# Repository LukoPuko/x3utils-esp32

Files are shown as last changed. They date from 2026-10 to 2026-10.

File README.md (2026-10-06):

# x3utils-esp32

A **standalone ESP32 flasher for the AT32F415 VCU** on X3-family e-scooters
(ZT3 Pro, Max G3, F3 / F3 Pro), controlled entirely from your **phone's browser
over WiFi**.

No PC. No ST-LINK. No app install. The ESP32 *is* the programmer: it bit-bangs
SWD to the scooter's debug pins itself, and hosts a web UI you drive from
Safari on an iPhone (or any browser — WiFi, so the Chrome/WebUSB limitation of
the original web app does not apply).

This is an ESP32 port of [**x3utils**](https://github.com/ztakis/x3utils). The
flashing *brains* — the AT32F415 erase/program/verify sequence, the FAP
read-protection check and rescue, the SHU-compatibility patch and its firmware
safety gates — are ported straight from the upstream engine. Only the transport
changed: an ESP32 GPIO SWD master replaces the ST-LINK, and a built-in web
server replaces the desktop GUI.

> [!WARNING]
> This tool writes the scooter VCU directly. A wrong file, a bad contact, or an
> interrupted flash can leave the controller unusable until recovered. **Always
> make a full backup first and keep it safe.** Use 3.3 V logic only, and power
> the VCU from **one** source at a time.

> [!IMPORTANT]
> **On-hardware validation status.** The firmware-identity / SHU-compat safety
> gates and the Thumb-2 version decoder are covered by host unit tests (see
> `host_test/`). The bit-banged SWD transaction layer (`swd.cpp`) follows the
> standard ADIv5 framing but has **not** been bench-verified against a real
> AT32F415 in this repository's CI (none exists). Treat your first connection as
> a bring-up: start with **Check connection** and **Backup**, confirm a clean
> 128 KB read, and only then flash. If you see `no ACK` / parity errors, raise
> the **SWD half-clock µs** setting (1–3) for a slower, more tolerant line.

---

## What it does

Same operations as the desktop/web app, from the browser:

- **Check connection** — read-only probe + target identification.
- **Backup 128 KB** — full dump, validated, downloaded to your phone as a `.bin`.
- **Backup + Flash** — upload a full 128 KB `.bin`; it erases, writes, verifies.
- **Flash slot 0** — upload a slot-0 `.bin` (identity-preserving).
- **Check protection** — read-only FAP (read-protection) verdict.
- **Unlock / Rescue** — clears FAP; this **mass-erases** main flash (recovery path).
- **Make SHU compatible** — dumps, patches the chip's own firmware at `0x1420`,
  and flashes it back. Safety-gated exactly like upstream: refuses non-factory
  firmware, XTEA-present (too-new) firmware, unsupported models (GT3), and
  blacklisted/unidentified versions.

Connection modes: **Default SWD**, **Under-reset (nRST)**, and **Power-race**
(hammer connect while you apply power).

---

## Hardware

### Option A — the X3-Tuner PCB (all-in-one)

[`hardware/`](hardware/) contains a ready-to-order board built only for this
job (documentation in German):
- **MCU:** ESP32-C3-WROOM-02 module, chosen as the cost-optimised option.
- **USB:** USB-C wired to the C3's native USB, so no USB-UART chip is needed.
- **Battery:** 1S LiPo with a TP4056 charger and DW01A protection.
- **VCU supply:** a GPIO-switched 3.3 V supply, so the firmware can run *Power-race* by itself.
- **Board:** 38 × 54.5 mm, two layers, all parts on one side.
- **Manufacturing files:** Gerber, BOM and CPL for JLCPCB assembly, plus a 10-up panel for volume orders.
- **Case:** a 3D-printable enclosure.

Build the firmware with `pio run -e x3tuner -t upload`.

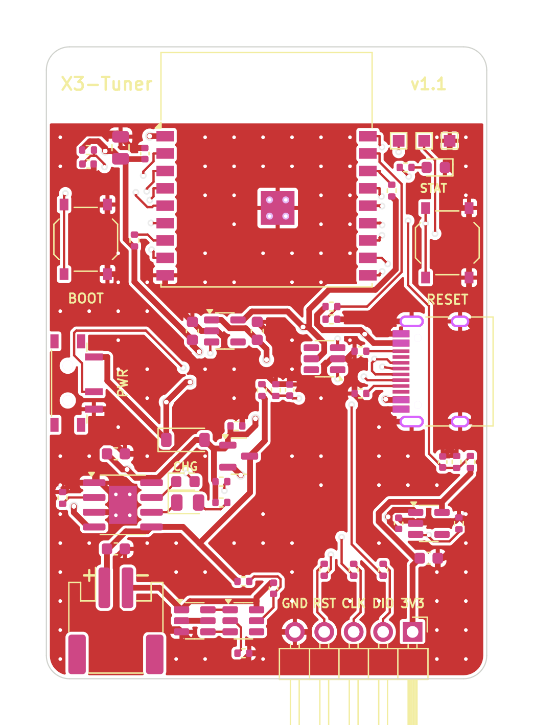
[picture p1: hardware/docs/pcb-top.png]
X3-Tuner PCB


### Option B — any ESP32 dev board

- An **ESP32** board (classic ESP32, or an S3 / C3 — see `platformio.ini`).
- Four wires to the scooter's debug header: **SWCLK**, **SWDIO**, **GND**, and
  **nRST / C45** (strongly recommended — needed for Under-reset mode and most
  reliable for locked/running targets).
- A 3.3 V power path for the VCU (bench/main power **or** the ESP32 3V3 pin —
  never both). See the upstream wiki's per-model guides for pad locations and
  the C45 point.

### Default pin map (classic ESP32 — change in `src/config.h` or the UI)

| Signal | GPIO |
|---|---|
| SWCLK  | 18 |
| SWDIO  | 19 |
| nRST | 21 |
| GND | any GND |

S3/C3 defaults are different — see `src/config.h`.

---

## Build & flash the ESP32

Uses [PlatformIO](https://platformio.org/).

```bash
# classic ESP32
pio run -e esp32dev -t upload

# or an S3 / C3 board
pio run -e esp32-s3 -t upload
# the X3-Tuner PCB from hardware/ (ESP32-C3, native USB)
pio run -e x3tuner -t upload
pio run -e esp32-c3 -t upload

# watch the serial log (shows the WiFi IP)
pio device monitor -b 115200
```

First boot creates a **WiFi hotspot**:

- SSID: `x3utils-esp32`  ·  password: `x3utils123`
- Join it from your phone, then open **http://192.168.4.1/** (or
  **http://x3utils.local/**).

To join your own network instead, open **Settings → WiFi → Join network** in the
UI, enter your SSID/password, and save (the ESP32 reboots and connects; find its
IP on the serial monitor or your router).

---

## Using it from your phone

1. Wire SWCLK / SWDIO / GND / nRST to the VCU, power the VCU from one source.
2. Join the ESP32 hotspot and open the page.
3. Pick a connection mode (start with **Default SWD**; use **Under-reset** if the
   firmware keeps SWD disabled while running).
4. **Check connection** → you should see the AT32F415 part identified.
5. **Backup 128 KB** → wait for "Backup complete", then **Download last backup**.
6. Only now flash: **Backup + Flash** / **Flash slot 0** (upload a `.bin`), or
   **Make SHU compatible**.

The console streams live log + progress over a WebSocket. **Abort** stops a
running operation (safe between steps; a flash in progress finishes its current
word).

---

## How the port works

The upstream engine is written against a tiny debug-probe surface — read/write a
debug register, read/write memory, drive nRST. `src/swd.cpp` provides exactly
that surface by bit-banging ADIv5 SWD on two GPIOs, so the AT32 flash algorithm
in `src/at32.cpp` is the *same* algorithm the desktop/web app runs:

```
browser ──HTTP/WebSocket──> ESP32 web server (main.cpp)
                                  │  queues one command
                                  ▼
                            x3_ops.cpp  (Check/Backup/Flash/Compat/Protection)
                                  │
                      at32.cpp (Cortex-M + AT32F415 flash)   fw_ident.cpp (SHU gates)
                                  │
                              swd.cpp  (bit-banged ADIv5 SWD)
                                  │  SWCLK / SWDIO / nRST
                                  ▼
                           AT32F415 VCU
```

The experimental SRAM flash loader from upstream is intentionally **not** ported;
this uses the field-proven direct word-write path. The SHU-compat patch,
factory-state check, XTEA gate, model allow-list, and the Thumb-2 version
blacklist/known-version decoder are ported faithfully in `src/fw_ident.cpp`.

### Source layout

```
src/
  config.h       pins, WiFi defaults, SWD timing, target geometry
  swd.{h,cpp}    bit-banged ADIv5 SWD master (the ST-LINK replacement)
  at32.{h,cpp}   Cortex-M debug + AT32F415 detect / erase / program / verify / FAP
  fw_ident.{h,cpp}  banner, factory-state, version matrix, SHU-compat gates
  x3_ops.{h,cpp} high-level operations driven by the UI
  web_ui.h       the mobile web UI (served from flash)
  main.cpp       WiFi + web server + WebSocket + routing + settings
host_test/            host unit tests for the safety gates (see below)
```

## Tests

The portable safety-critical logic has host-side unit tests (no hardware, no
ESP toolchain needed):

```bash
cd host_test
g++ -std=gnu++17 -I shim -I ../src test_fwident.cpp ../src/fw_ident.cpp -o t && ./t
```

They cover the Thumb-2 version decoder, the blacklist floor, the XTEA / factory
/ already-compatible / unidentified refusals, the MCU model requirement, and the
16-byte compat patch.

---

## Credits & license

MIT. Ported from [x3utils](https://github.com/ztakis/x3utils) (© ztakis) and its
swdart engine (© nopbxlr). See [LICENSE](LICENSE). Supported models and the
firmware version matrix mirror upstream; consult the upstream wiki for wiring,
C45 locations, and SHU-compat firmware limits.

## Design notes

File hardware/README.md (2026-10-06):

# X3-Tuner – eigene Platine für x3utils-esp32

Ein **All-in-one-Gerät** für die AT32F415-VCU der X3-Scooter-Familie (ZT3 Pro,
Max G3, F3 / F3 Pro): ESP32-C3 (Spar-Version), eigener Akku mit Lade- und
Schutzschaltung, schaltbare 3,3-V-Versorgung für die VCU und ein SWD-Stecker.
Ersetzt **ST-LINK, PC und Kabelsalat** – bedient wird alles per Handy-Browser
über WLAN (Firmware: dieses Repository, Environment `x3tuner`).

| Oberseite | Unterseite |
|---|---|
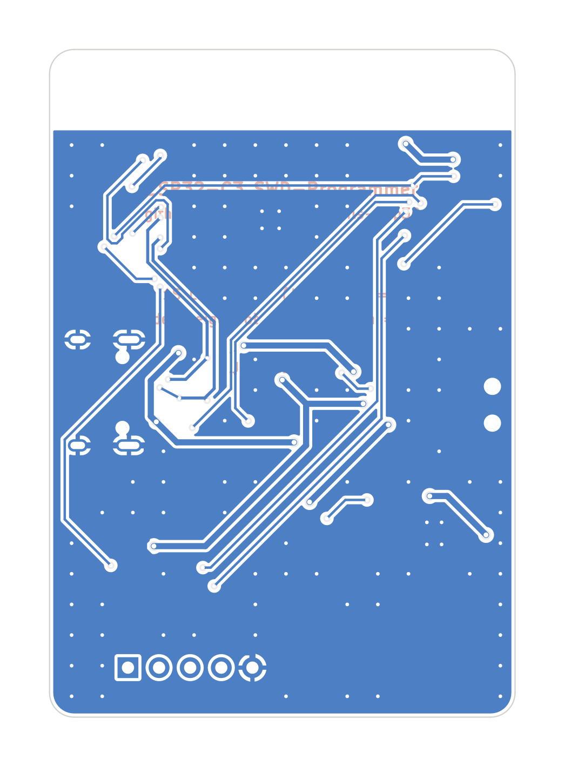
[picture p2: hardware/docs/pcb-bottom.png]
Unterseite
| Oberseite |  |

[Schaltplan (PDF)](docs/x3tuner-schematic.pdf) ·
[Bestückungsplan (PDF)](docs/x3tuner-assembly.pdf) ·
[Fertigungsdaten](production/) ·
[3D-Druck-Gehäuse](case/)

> [!IMPORTANT]
> **Status: Design fertig (Rev. 1.1, Spar-Version mit ESP32-C3), noch nicht gefertigt.** Die Platine besteht den
> KiCad-DRC (0 Fehler, 0 offene Verbindungen) und der Schaltplan wird
> automatisch gegen die Netzliste geprüft – ein gebauter Prototyp existiert
> aber noch nicht. Bitte zuerst **2–5 Stück** bestellen und testen. Was du vor
> der Bestellung prüfen solltest, steht unter [Vor der Bestellung prüfen](#vor-der-bestellung-prüfen).

---

## Was drauf ist

| Block | Lösung | Warum |
|---|---|---|
| MCU | **ESP32-C3-WROOM-02-N4**: 4 MB Flash, 400 KB RAM, WLAN + BLE | ca. 1,20–1,55 $ günstiger als der S3; die Firmware braucht nur 128 KB Puffer |
| USB | USB-C direkt an GPIO18/19 (natives USB des C3) | kein CH340/CP2102 nötig → günstiger |
| Laden | **TP4056**, ca. 360 mA (R4 = 3,3 kΩ), LEDs rot = lädt, grün = voll | Standard, sehr billig |
| Akku-Schutz (BMS) | **DW01A + 8205-Dual-MOSFET** | Schutz vor Über- und Tiefentladung, Überstrom und Kurzschluss |
| Power-Path | P-MOSFET AO3401A + Schottky B5819W | mit USB läuft das Gerät aus USB, der Akku wird nur geladen |
| 3,3 V ESP | ME6211 (500 mA LDO), Ein/Aus-Schiebeschalter **MSK12C02** am Enable-Pin | kleiner Ruhestrom, Laden auch im ausgeschalteten Zustand; Schalter ca. 0,05 $ |
| 3,3 V VCU | **zweiter ME6211, per GPIO10 schaltbar**, mit Spannungsmessung | Firmware schaltet die VCU selbst ein → **automatischer Power-Race** |
| SWD | 1×5-Stiftleiste 2,54 mm (3V3 · DIO · CLK · RST · GND), 100 Ω Serienwiderstände | Dupont-Kabel wie beim ST-LINK |
| Bedienung | RESET, BOOT, Status-LED (weiß) | |
| Messung | Akkuspannung, USB vorhanden, Spannung an der VCU (alle ADC1) | Akkuanzeige in der Web-Oberfläche, Schutz gegen Doppelversorgung |

**Platine:** 38 × 54,5 mm, 2 Lagen, 1,6 mm, alle Teile auf der Oberseite
(einseitige Bestückung = günstig). JLC bestückt **alles**, auch die
SWD-Stiftleiste – von Hand gelötet wird nichts. Unten durchgehende Massefläche – dort klebt
der Akku. Antenne am oberen Rand, ohne Kupfer darunter.

### Pinbelegung ESP32-C3-WROOM-02

| GPIO | Funktion | | GPIO | Funktion |
|---|---|---|---|---|
| IO5 | SWCLK (über 100 Ω) | | IO3 | VTGT_SENSE (Spannung an der VCU, ½) |
| IO6 | SWDIO (über 100 Ω) | | IO1 | VBUS_SENSE (USB steckt, ½) |
| IO7 | nRST (zur VCU, über 100 Ω) | | IO4 | VBAT_SENSE (Akkuspannung, ½) |
| IO10 | TGT_EN (VCU-Versorgung ein) | | IO0 | Status-LED |
| IO9 | BOOT-Taste | | IO18/19 | USB D−/D+ |
| EN | RESET-Taste | | IO20/21 | UART0 (Testpads TP2/TP1) |
| IO2, IO8 | Strapping-Pins, je 10 kΩ nach 3,3 V | | | |

Die SWD-Pins liegen links am Modul, auf der Seite des Steckers. Alle
Messeingänge sind ADC1, denn ADC2 funktioniert beim C3 nicht, solange WLAN läuft.

### SWD-Stecker J3 (von links nach rechts, Oberseite)

| GND | RST | CLK | DIO | 3V3 |
|---|---|---|---|---|
| Masse | nRST / C45 | SWCLK | SWDIO | 3,3 V **vom Gerät** (schaltbar) – oder Messeingang, wenn die VCU anders versorgt wird |

> [!WARNING]
> Die 3V3-Leitung ist ein **Ausgang**. Hängt die VCU schon an Fahrakku oder
> Netzteil, schaltet die Firmware die eigene Versorgung **nicht** ein (sie misst
> die Spannung vorher). Trotzdem gilt wie beim ST-LINK: immer nur **eine**
> Stromquelle für die VCU.

### Bedienelemente

| Teil | Funktion |
|---|---|
| Schiebeschalter (links, „PWR") | Gerät ein/aus. Geladen wird auch im ausgeschalteten Zustand. |
| RESET (rechts) | ESP32 neu starten |
| BOOT (links) | beim Reset halten = Download-Modus (nur bei „verflashter" Firmware nötig) |
| LED „CHG" rot / grün | lädt / voll (TP4056) |
| LED „STAT" weiß | kurzes Blitzen alle 2 s = bereit, schnelles Blinken = Vorgang läuft |

---

### Warum ein fertiges Modul und kein nackter ESP32-C3-Chip?

Live-Preise von jlcpcb.com, Stand 6.10.2026, jeweils der 1+-Preis:

| | WROOM-02 (Modul) | nackter Chip ESP32-C3FH4 |
|---|---|---|
| Funkchip | 3,29 $ (alles drin) | 2,09 $ |
| 40-MHz-Quarz | im Modul | 0,11 $, *Extended* (kein Basic-Quarz mit 40 MHz) |
| Antenne | im Modul | Leiterbahn-Antenne; Chip-Antennen bei JLC nicht auf Lager |
| HF-Anpassung (Spule 2,7 nH + Kondensator 1,8 pF) | im Modul | je *Extended* |
| **Teile pro Platine** | **3,29 $** | **≈ 2,25 $** |
| Extended-Gebühren pro Auftrag | 3 $ | 12 $ (Chip, Quarz, Spule, Kondensator) |
| Funkzulassung (CE/RED) | Modul ist zertifiziert, Funkprüfberichte nutzbar | eigene Funkprüfung im Labor, ca. 3.000–8.000 € |
| Platine | 2 Lagen reichen | Espressif empfiehlt 4 Lagen und 50-Ω-Leitungen. Die Antenne muss mit einem Netzwerkanalysator abgestimmt werden |

Der nackte Chip spart ca. 1 $ pro Platine, kostet aber 9 $ mehr Gebühren pro
Auftrag. Bei 5 Platinen wird es dadurch **teurer**, erst ab ca. 10 Stück gleicht
sich das aus. Für ein Gerät, das verkauft werden soll, kommt die eigene
Funkprüfung dazu. Sie lohnt sich erst bei vielen tausend Stück. Deshalb bleibt es beim Modul.
Das kleinere ESP32-C3-MINI-1 kostet 3,03 $, also nur 0,26 $ weniger, braucht aber ein neues Layout.

## Akku

* **1S-LiPo 3,7 V mit JST-PH-2,0-Stecker**, Bauform **503040** (≈ 30 × 40 × 5 mm,
  ~600 mAh). Er passt unter die Platine und ins Gehäuse. Laufzeit ca. 4–6 h WLAN-Betrieb
  (der C3 braucht weniger Strom als der S3). Größer als 34 × 43 mm passt nicht
  mehr unter die 54,5-mm-Platine.
* Ladestrom ist mit R4 = 3,3 kΩ auf ~360 mA eingestellt → Akku **≥ 400 mAh**.
  Für kleinere Akkus R4 vergrößern (4,7 kΩ ≈ 255 mA, 10 kΩ ≈ 120 mA).
* ⚠️ **Polarität prüfen!** Bei JST-PH-Akkus ist die Belegung nicht einheitlich.
  Auf der Platine: **„+" = Pin 1 = links**, „−" = rechts (siehe Aufdruck).
  Falsch herum zerstört den Lader. Notfalls die Crimpkontakte im Stecker umstecken.

---

## Wo fertigen lassen? (Platine + Bestückung, Lieferung nach Deutschland)

### JLCPCB – Live-Preise vom 6. Oktober 2026

Alle Bauteilpreise, Lagerbestände, der Platinenpreis und der Versand stammen
direkt von jlcpcb.com, die Gebühren aus JLCs Hilfe-Artikeln
([PCB Assembly Price](https://jlcpcb.com/help/article/pcb-assembly-price),
[PCB Assembly FAQs](https://jlcpcb.com/help/article/pcb-assembly-faqs)).
Die Bestückungszeilen zeigt JLC erst nach dem Hochladen von BOM und CPL im
eingeloggten Warenkorb. Sie sind hier deshalb mit diesen Preisen nachgerechnet,
inklusive der Mindest- und Ausschussmengen pro Bauteil. JLC bestückt **alle**
Teile, du lötest nichts selbst.

| Economic-Bestückung, alles bestückt | 2 Stück | 5 Stück |
|---|---|---|
| Bauteile | 13,20 $ | 27,59 $ |
| Einrichtung 8,18 $ + Schablone 1,53 $ | 9,71 $ | 9,71 $ |
| Extended-Gebühr: 10 Sorten × 3 $ | 30,00 $ | 30,00 $ |
| Handlöten der Stiftleiste J3 (THT, pro Auftrag) | 3,58 $ | 3,58 $ |
| Lötstellen (0,0016 $ pro Lötstelle) | 0,61 $ | 1,52 $ |
| **Bestückung netto** | **57,10 $** | **72,40 $** |
| Platine (5 Stück, 2 Lagen, HASL) | 4,00 $ | 4,00 $ |
| Versand „Global Standard Direct Line" (8–13 Tage) | 6,41 $ | 6,41 $ |
| **Gesamt inkl. 19 % MwSt.** | **≈ 80 $ ≈ 69 €** | **≈ 99 $ ≈ 85 €** |

Damit kostet jede Platine bei 5 Stück ca. 17 €, bei 10 Stück ca. 11 € und bei 50 Stück ca. 6 €.
Express-Versand (UPS/DHL/FedEx, DDP) kostet 27–32 $ statt 6,41 $.

**Warum Kleinserien so teuer sind:** Die festen Gebühren von ca. 43 $
pro Auftrag machen bei 2–5 Platinen mehr als die Hälfte aus. Allein 30 $ davon
ist die Extended-Gebühr. Diese 10 Teile gibt es bei JLC nur als „Extended":

- ESP32-C3-Modul, DW01A, HJ8205, TP4056 und ME6211
- SRV05-4, USB-C-Buchse, JST-Buchse, Schiebeschalter und Stiftleiste

Am 6.10.2026 habe ich für jedes davon im JLC-Katalog nach einem gebührenfreien
„Basic"-Ersatz gesucht. Es gibt keinen. Ab 100 Stück fallen diese
Gebühren kaum noch ins Gewicht, siehe unten.

**In dieser Revision geändert, weil es die Bestellung verteuert oder blockiert hat:**
- **ESD-Schutz U6:** Die ProTek SRV05-4 (C85364) war nicht lieferbar. Es gab nur
  Vorbestellung mit 30 Stück Mindestmenge. Jetzt ist die baugleiche
  TECH-PUBLIC SRV05-4 (C558418) drin: 219.000 Stück auf Lager, 0,03 $.
- **Status-LED D4:** Statt der gelben LED (Extended, +3 $) ist eine weiße
  KT-0603W (C2290, Basic, ohne Gebühr) verbaut, mit Vorwiderstand 100 Ω.
- **Stiftleiste J3:** wird jetzt von JLC mitbestückt
  (C32713264, gewinkelt 1×5, 2,54 mm).

### Am günstigsten für die erste Bestellung: NextPCB „Rev 0"

NextPCB bestückt die **erste Bestellung kostenlos** (bis 500 $), und die
Platine kostet beim ersten Auftrag 0,10 $. Bezahlt werden nur Bauteile und
Versand. Stand 6.10.2026, live auf
[nextpcb.com/rev0-pcba](https://www.nextpcb.com/rev0-pcba) geprüft. Die Bedingungen:

- 5 oder 10 Stück, nur eine Bestellung pro Kunde, grüne Lötmaske, FR4.
- Platine mindestens **50 × 50 mm**. Deshalb gibt es eine eigene Variante mit
  zwei abbrechbaren Randstreifen links und rechts (52 × 54,6 mm), siehe
  [`production/nextpcb/`](production/nextpcb/). Die Streifen werden nach der
  Lieferung abgebrochen, wie beim 10er-Nutzen.
- Es gehen nur Bauteile, die bei HQ Online (dem NextPCB-Bauteilshop) auf Lager sind.
  Am 6.10.2026 waren alle Teile vorrätig, das ESP32-Modul z. B. mit 3.771 Stück zu 3,42 $.

| NextPCB „Rev 0", 5 Stück, alles bestückt | |
|---|---|
| ESP32-C3-Modul, 5 × 3,42 $ | 17,11 $ |
| übrige Hauptteile inkl. Mindestmengen | 5,53 $ |
| Widerstände, Kondensatoren, LEDs (geschätzt) | ≈ 3,50 $ |
| Bestückung, Einrichtung | 0,00 $ |
| Platine | 0,10 $ |
| Versand nach Deutschland (erst im Konto sichtbar, geschätzt) | ≈ 10–20 $ |
| **Gesamt inkl. 19 % MwSt.** | **≈ 37–47 €** |

Hochladen: `x3tuner-nextpcb-gerbers.zip`, `x3tuner-nextpcb-bom.csv` (mit
Hersteller-Teilenummern) und `x3tuner-nextpcb-cpl.csv`. Die Drehungen im CPL folgen dem
KiCad-Standard, ohne JLC-Korrekturen. Prüfe sie trotzdem in der NextPCB-Vorschau.

**Unter 35 € für 5 fertige Platinen geht es nicht.** Allein die 5 ESP32-Module
kosten ca. 17 € und der Versand 10–20 €. Wer nur die Firmware
testen will, nimmt ein ESP32-C3-SuperMini mit bereits eingelöteten Stiftleisten
(Firmware-Umgebung `esp32-c3`), 5 Dupont-Kabel und eine Powerbank – ohne Löten,
für ca. 5–8 €.

**Andere Anbieter** (frühere Schätzungen, nicht live geprüft):

| Anbieter | 5 Stück | 10 Stück | 50 Stück | Anmerkung |
|---|---|---|---|---|
| **JLCPCB** (Economic, live) | **≈ 17 €/Stk.** | **≈ 11 €/Stk.** | **≈ 6 €/Stk.** | **Empfehlung**, alle Teile ab Lager |
| PCBWay | ≈ 16 $ | ≈ 11 $ | ≈ 7–8 $ | 29 $ Einrichtung (Aktion) |
| AISLER (Deutschland) | ≈ 50 € | ≈ 30 € | ≈ 11 € | kein Zoll, aber 7,50 € je Bauteilsorte |

> [!NOTE]
> **Zoll seit 1. Juli 2026:** Auf Pakete bis 150 € kommt in der EU eine Zollgebühr von 3 € pro Warenposition.
> JLC und PCBWay erheben die MwSt. über IOSS direkt an der Kasse. Bei größeren
> Bestellungen (über 150 €) den **DDP**-Versand wählen, sonst kassiert der
> Paketdienst MwSt. und Gebühr (ca. 15 €) bei der Zustellung.

### Bestellen bei JLCPCB – Schritt für Schritt

Alle Dateien liegen fertig in [`production/`](production/):

| Datei | Wofür |
|---|---|
| `x3tuner-gerbers.zip` | Gerber + Bohrdaten → beim PCB-Upload |
| `x3tuner-bom.csv` | Stückliste mit LCSC-Nummern → bei „PCB Assembly" |
| `x3tuner-cpl.csv` | Bestückungspositionen → bei „PCB Assembly" |
| `x3tuner-bom-generic.csv` | herstellerneutrale Stückliste (Hersteller-Teilenummern) für NextPCB, PCBWay & Co. |

1. Auf jlcpcb.com `x3tuner-gerbers.zip` hochladen. Standard-Einstellungen
   reichen: **2 Lagen, 1,6 mm, HASL bleifrei**, beliebige Lötstoppfarbe.
2. **PCB Assembly** aktivieren → **Economic**, **Top Side**, Menge 2, 5 oder 10.
   Keine Zusatzoptionen anhaken (Reinigung, Fotobestätigung, Backen usw. kosten extra).
3. BOM und CPL hochladen. Alle Teile sollten automatisch zugeordnet werden.
4. In der Bauteil-Vorschau **jede Drehung prüfen**, besonders die ICs
   (U2, U3, U4, U5, U6, Q1, Q2), die LEDs, J2 und die Stiftleiste J3
   (die Pins müssen über die Platinenkante hinausragen). Das CPL enthält schon die
   üblichen JLC-Korrekturen für SOT-23 und SOIC – kontrolliere sie trotzdem in der Vorschau.
5. Alle Teile stehen in der BOM. JLC lötet auch die Stiftleiste J3 ein
   (THT, 3,58 $ Handlöt-Pauschale pro Auftrag). Nur der Akku wird später
   eingesteckt.
6. An der Kasse den **SMT-Gutschein** einlösen: Neukunden bekommen 10 $, außerdem
   gibt es jeden Monat 9 $, was die Einrichtungsgebühr deckt. Pro Auftrag gilt
   ein Gutschein.

---

## Größere Stückzahlen: 100–200 und 500 Stück

**Wichtig:** JLCs günstige *Economic*-Bestückung nimmt nur **2–50 Stück pro
Auftrag**. Die *Standard*-Bestückung verlangt mindestens 70 × 70 mm, die
Platine hat aber nur 38 × 54,5 mm. Deshalb gibt es einen fertigen **Nutzen
(Panel) mit 10 Platinen** in [`production/panel/`](production/panel/):

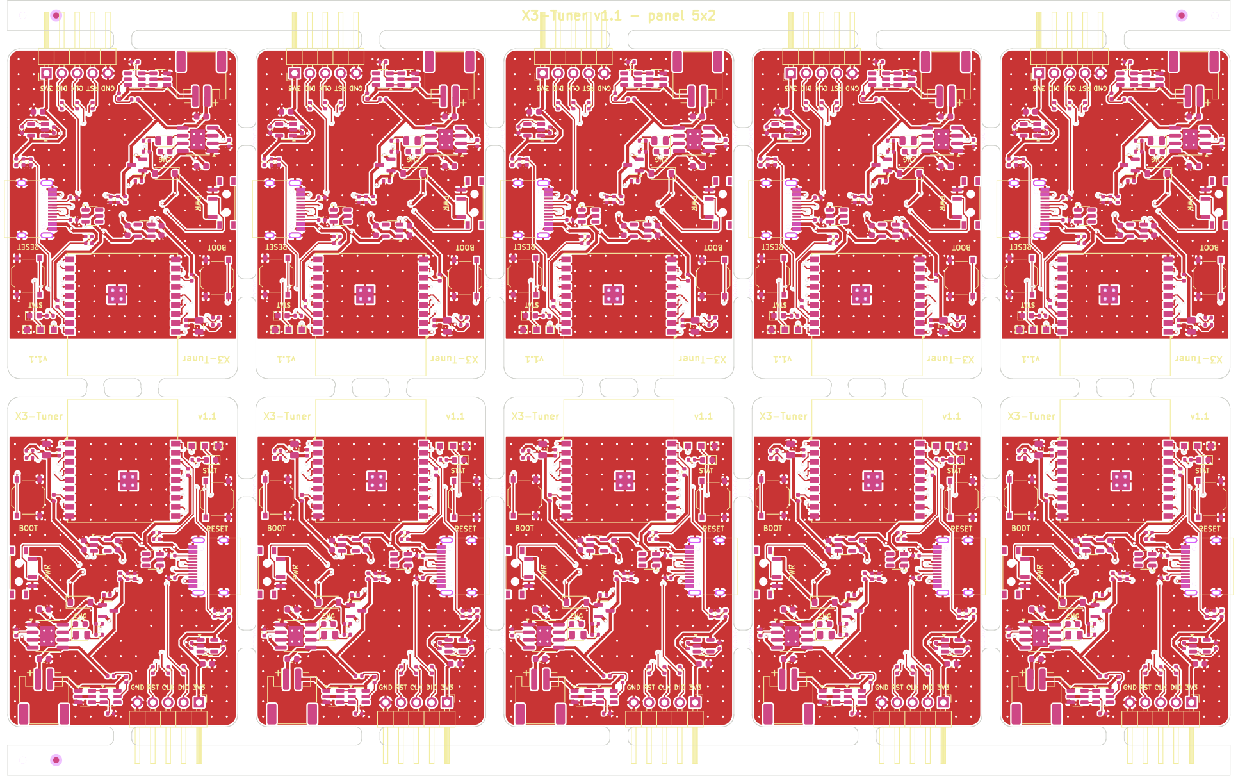
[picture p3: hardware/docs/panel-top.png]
Panel 5x2


* 5 × 2 Platinen auf 202 × 128 mm, 3 mm gefräste Spalte, Abbrechstege mit
  Mouse-Bites, Randstreifen mit 3 Passermarken und 3 Werkzeugbohrungen.
* Die Stege sitzen bewusst **nicht** an USB-C, Schalter oder SWD-Stecker,
  damit nach dem Abbrechen kein Grat ins Gehäuse drückt.
* Die obere Reihe ist um 180° gedreht, so zeigen alle SWD-Kanten zu den Randstreifen.
* Bestellmenge in **Panels**: 100 Stück = 10, 200 Stück = 20, 500 Stück = 50
  Panels. Damit ist alles im Economic-Tarif, 500 ist genau das Maximum.
* Upload genau wie bei der Einzelplatine, nur mit `x3tuner-panel-gerbers.zip`,
  `x3tuner-panel-bom.csv` und `x3tuner-panel-cpl.csv`.
  Option „Panel by JLCPCB" **nicht** wählen, das Panel ist schon fertig.

### Kosten pro Platine (bestückt, ab Werk JLCPCB, Lieferung nach Deutschland)

Bauteilpreise live von jlcpcb.com (6.10.2026, Staffelpreise je Menge), Gebühren
laut JLC-Hilfe, Platine und Versand geschätzt (±20 %). Annahmen:
- **ESP32-C3-WROOM-02-N4:** 2,42 $ ab 100 Stück (JLC-Lager: 11.466 Stück).
- **Übrige Teile:** ca. 1,20 $, inklusive Stiftleiste.
- **Löten:** ca. 190 Lötstellen × 0,0016 $.
- **Fixkosten pro Auftrag:** 43,29 $. Das sind Einrichtung, Schablone, 10 Extended-Sorten und die Handlöt-Pauschale für J3.
- **Versand:** DHL Express (DDP).

| | 100 Stück | 200 Stück | 500 Stück |
|---|---|---|---|
| Bauteile | ≈ 3,83 $ | ≈ 3,65 $ | ≈ 3,60 $ |
| Bestückung (Lötstellen) | 0,30 $ | 0,30 $ | 0,30 $ |
| Fixkosten anteilig | 0,43 $ | 0,22 $ | 0,09 $ |
| Leiterplatte (Panels) | ≈ 0,28 $ | ≈ 0,23 $ | ≈ 0,18 $ |
| Versand + Verzollung | ≈ 0,42 $ | ≈ 0,28 $ | ≈ 0,18 $ |
| **Summe netto** | **≈ 5,25 $** | **≈ 4,70 $** | **≈ 4,35 $** |
| **inkl. 19 % Einfuhr-USt.** | **≈ 6,25 $ ≈ 5,40 €** | **≈ 5,55 $ ≈ 4,80 €** | **≈ 5,20 $ ≈ 4,45 €** |
| **Gesamtbetrag** | **≈ 625 $** | **≈ 1.115 $** | **≈ 2.590 $** |

Zum Vergleich die erste Version mit ESP32-S3 (8 MB PSRAM) und C&K-Schalter, damals
geschätzt: ≈ 7,50 / 7,10 / 6,80 $ pro Platine. Die Spar-Version kostet also rund **20 % weniger**.

Über 150 € Warenwert gilt die normale Einfuhr: 19 % Einfuhrumsatzsteuer, für
Firmen als Vorsteuer erstattbar, plus Verzollungsgebühr des Paketdiensts.
Für bestückte Leiterplatten fällt in der Regel kein Zoll an. **DDP**-Versand
wählen, dann ist alles vorab bezahlt.

### Komplettgerät (Platine + Akku + Gehäuse)

| Posten | 100–200 Stück | 500 Stück |
|---|---|---|
| Platine bestückt, inkl. Stiftleiste (inkl. USt.) | ≈ 5,55–6,25 $ | ≈ 5,20 $ |
| Akku 503040 (≈ 600 mAh) mit JST-PH | ≈ 1,50–2,50 $ (Herstellerangebot einholen) | ≈ 1,50–2 $ |
| Gehäuse | selbst gedruckt ≈ 0,30 € Material, aber 1,5–2 h Druckzeit pro Stück | Druckdienst oder Druckfarm, ca. 2–4 $ (Angebot einholen) |
| **≈ Material pro Gerät** | **≈ 7,50–9 $** | **≈ 8,50–11 $** mit Druckdienst, selbst gedruckt ≈ 7 $ |

Gelötet wird nichts. Pro Gerät kommen ca. 3–5 Minuten Montage dazu: Firmware
flashen, testen, Akku einstecken, Deckel aufklicken. Ein Spritzguss-Gehäuse
(Werkzeug ca. 3.000–8.000 €) lohnt sich erst ab einigen tausend Stück.

> [!IMPORTANT]
> **Wenn du die Geräte verkaufen willst**, brauchst du in Deutschland/EU vorher:
> - eine CE-Konformitätserklärung nach Funkanlagen-Richtlinie (RED), EMV und RoHS. Die
>   Zertifikate des ESP32-Moduls helfen, ersetzen sie aber nicht.
> - eine **WEEE-Registrierung** bei der stiftung ear.
> - eine Akku-Registrierung nach Batterierecht.
> - eine Verpackungsregistrierung (LUCID).
>
> Lithium-Akkus brauchen beim Versand UN38.3-Unterlagen. Außerdem verliert ein
> getunter E-Scooter in Deutschland auf öffentlichen Straßen seine
> Betriebserlaubnis (eKFV) und den Versicherungsschutz. Ein Gerät, das als
> „Tuning"-Werkzeug beworben wird, kann deshalb rechtliche Risiken bringen.
> Kläre das vor einem Verkauf ab.

---

## Gehäuse

Ein passendes, schraubenloses **3D-Druck-Gehäuse** inklusive Akkufach liegt in
[`case/`](case/). Es ist facettiert im „Stick"-Look, ca. **42 × 68 × 17 mm** groß
und hat Lichtschlitze, Pin-Löcher für RESET/BOOT und eine gravierte SWD-Belegung.
Druck- und Montageanleitung stehen in [`case/README.md`](case/README.md).

| Zusammengebaut | Durchsichtig (Aufbau) | Schnitt |
|---|---|---|
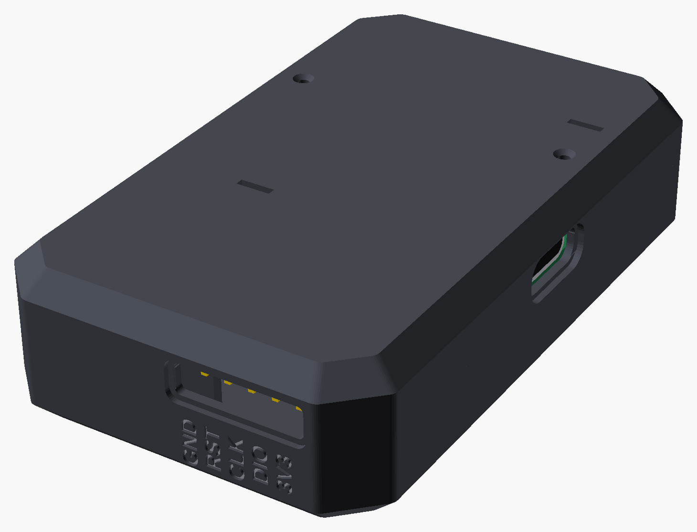
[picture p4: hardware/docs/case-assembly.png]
Gehäuse
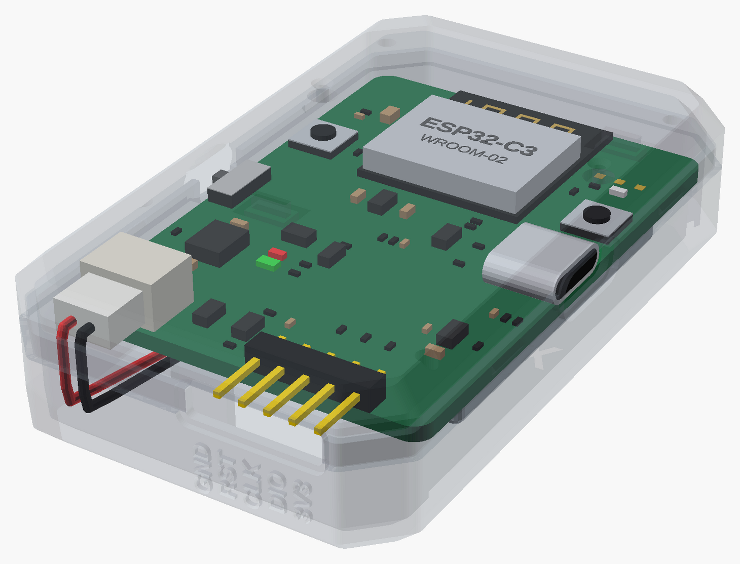
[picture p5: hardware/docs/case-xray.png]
Röntgenansicht
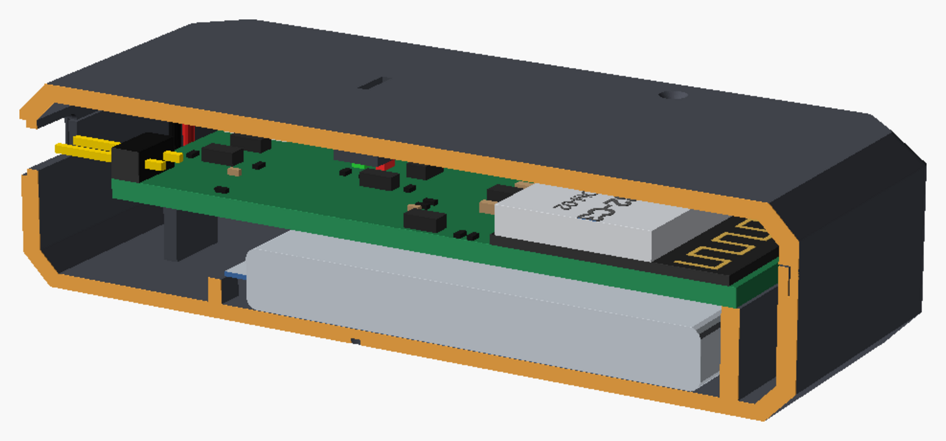
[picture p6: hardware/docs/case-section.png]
Schnitt
|  |  |  |

---

## Vor der Bestellung prüfen

Ehrliche Liste, was in dieser Umgebung **nicht** direkt verifiziert werden konnte:

* **LCSC-Nummern:** Alle 27 Positionen wurden am 6.10.2026 live auf jlcpcb.com
  geprüft: Typ, Lagerbestand, Preis, Basic/Extended. Alle sind ab Lager
  lieferbar. Kontrolliere die Lagerbestände trotzdem kurz vor der Bestellung.
  Knapp ist vor allem das ESP32-Modul mit 11.466 Stück.
* **Stiftleiste J3 (C32713264):** Das ist eine Standard-Stiftleiste (2,54 mm, gewinkelt). Ihre Maße
  habe ich nicht im Datenblatt gegengeprüft. In der JLC-Vorschau sollten die Pins
  über die Platinenkante zeigen, sonst die Drehung im CPL um 180° ändern.
* **HJ8205 (Q2) Pinbelegung** (1 = S1, 2 = D, 3 = S2, 4 = G2, 5 = D, 6 = G1)
  stammt aus zwei übereinstimmenden EasyEDA-Symbolen. Kurz mit dem Datenblatt
  abgleichen. Pin-kompatible Alternative: FS8205A im SOT-23-6 (C908265).
* **ESP32-C3-WROOM-02 Pinbelegung:**
  - 1 3V3, 2 EN, 3–8 IO4–IO9, 9 GND
  - 10 IO10, 11 RXD, 12 TXD, 13 IO18, 14 IO19
  - 15 IO3, 16 IO2, 17 IO1, 18 IO0, 19 EPAD/GND

  Die Belegung stammt aus dem Espressif-Datenblatt, wurde hier aber nicht noch einmal gegengelesen.
  Der Footprint kommt aus der KiCad-Bibliothek. Kurz mit dem Datenblatt abgleichen.
* **Schiebeschalter MSK12C02 (C431540):** Den Land-Pattern habe ich nach dem
  EasyEDA-Footprint gezeichnet, den JLC selbst für C431540 verwendet. Ein Datenblatt war nicht erreichbar.
  Prüfe in der JLC-Vorschau, ob der Schalter auf den Pads sitzt. Der Hebel steht nur
  ca. 1 mm über den Platinenrand hinaus, im Gehäuse bedienst du ihn mit dem Fingernagel in der Griffmulde.
* **Drehungen im CPL** – siehe Schritt 4 oben.
* **Schiebeschalter**: welche Stellung „EIN" ist, hängt von der Einbaurichtung
  ab. Einfach ausprobieren; es ist nur mit „PWR" beschriftet.
* Die **Firmware** für `x3tuner` konnte hier nicht komplett gebaut werden, weil
  die PlatformIO-Registry blockiert war. Die neuen Dateien wurden mit dem
  Host-Compiler geprüft und die Board-Logik ist per Unit-Test abgedeckt.

---

## Inbetriebnahme

1. Akku anstecken (Polarität!), USB-C einstecken → rote LED = lädt.
2. Schalter auf EIN. Firmware flashen:
   ```bash
   pio run -e x3tuner -t upload
   ```
   Wird kein Port gefunden: **BOOT gedrückt halten und RESET drücken**, dann
   meldet sich der ESP32-C3 als USB-Gerät für den Upload.
3. Mit dem WLAN **`x3utils-esp32`** (Passwort `x3utils123`) verbinden und
   **http://192.168.4.1/** öffnen. Die Karte „X3-Tuner" zeigt Akku, USB und die
   Spannung an der VCU.
4. SWD-Kabel an die VCU (GND, nRST/C45, SWCLK, SWDIO, 3V3).
   * VCU **ohne** Fahrakku: Button **„VCU power ON"** – das Gerät versorgt die VCU.
   * Modus **Power-race**: das Gerät schaltet die VCU selbst aus, lässt sie
     entladen und schaltet sie wieder ein, während es die Verbindung aufbaut.
     Den Stecker muss man dafür nicht mehr ziehen.
5. Wie gewohnt: **Check connection → Backup → erst dann flashen.**

Neu in der Firmware für diese Platine: `GET /api/status` liefert zusätzlich
`vbat`, `bat`, `usb`, `vtgt`, `tgtPower`; `POST /api/target {"on":true|false}`
schaltet die VCU-Versorgung.

---

## Dateien & Neu-Generieren

```
hardware/
├── gen/circuit.py        ← EINZIGE Quelle: Bauteile, Netze, Positionen, LCSC-Nummern
├── gen/make_sch.py       Schaltplan (.kicad_sch) + Projekt-Symbolbibliothek
├── gen/check_netlist.py  prüft die KiCad-Netzliste des Schaltplans gegen circuit.py
├── gen/make_pcb.py       Platine: Platzierung, USB-Vorverdrahtung, DSN/SES, GND-Flächen, Stitching
├── gen/drc.py            KiCad-DRC
├── gen/make_fab.py       Gerber/Bohrdaten, BOM, CPL, PDFs, Bilder
├── gen/build.sh          alles in einem Rutsch
├── gen/make_case.sh      Gehäuse: Positionen aus circuit.py → STL, Renderings, Maßblatt (OpenSCAD)
├── kicad/                KiCad-7-Projekt (mit KiCad 7 oder neuer öffnen und bearbeiten)
├── gen/make_panel.py     10er-Nutzen für Serien (KiKit; KIKIT=/pfad/zu/kikit)
├── gen/make_nextpcb.py   Einzelplatine mit Randstreifen für NextPCB „Rev 0" (KiKit)
├── production/           Fertigungsdaten (JLCPCB + herstellerneutrale Stückliste)
│   ├── panel/            Fertigungsdaten für den 10er-Nutzen (100–500 Stück)
│   └── nextpcb/          Fertigungsdaten für NextPCB „Rev 0" (erste Bestellung, 5 Stück)
├── case/                 3D-Druck-Gehäuse (OpenSCAD + STL)
└── docs/                 Schaltplan-PDF, Bestückungsplan, Renderings
```

Die KiCad-Dateien lassen sich ganz normal in KiCad öffnen und von Hand
weiterbearbeiten. Wer lieber am Generator ändert: `circuit.py` anpassen und
`gen/build.sh` laufen lassen. Dafür brauchst du KiCad 7 (`kicad-cli` und das Python-Modul `pcbnew`), Java 17+,
[Freerouting 1.9](https://github.com/freerouting/freerouting/releases) (`FREEROUTING=/pfad/zur.jar`),
`xvfb-run`, `rsvg-convert` und ImageMagick. Mit `SKIP_ROUTE=1` wird das
mitgelieferte Routing (`kicad/x3tuner.ses`) wiederverwendet.

Lizenz wie das Repository (MIT).

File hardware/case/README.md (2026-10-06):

# X3-Tuner Gehäuse (3D-Druck)

Zweiteiliges Rast-Gehäuse im **facettierten „Stick"-Design** für die
X3-Tuner-Platine **plus Akku**, ohne Schrauben. Es hat eine flache Ober- und
Unterseite, 45°-Fasen an allen Kanten und abgeschrägte Ecken. Gedruckt wird
es am besten in mattem Schwarz. Außenmaß **ca. 42 × 68 × 17 mm**.

| Zusammengebaut | Durchsichtig (Aufbau) |
|---|---|
| Gehäuse | Röntgenansicht |
| **Schnitt: Schichtaufbau** | **Von unten: Akku und Kabelführung** |
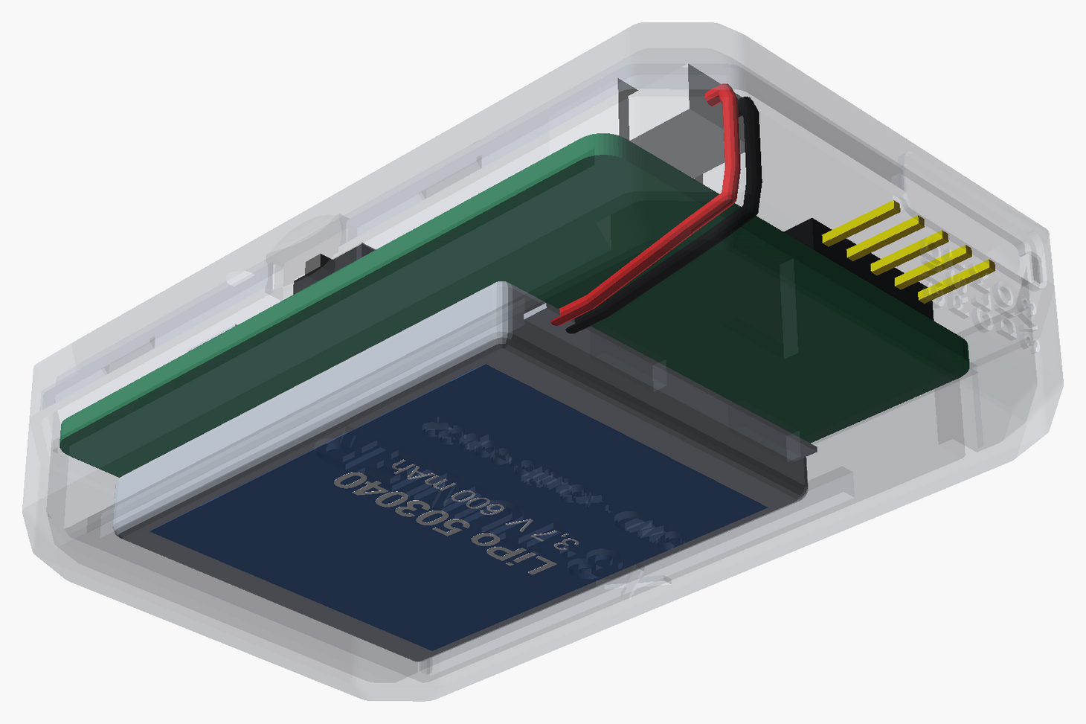
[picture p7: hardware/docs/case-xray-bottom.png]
Röntgenansicht von unten
| Schnitt |  |
| **Explosionsansicht** | |
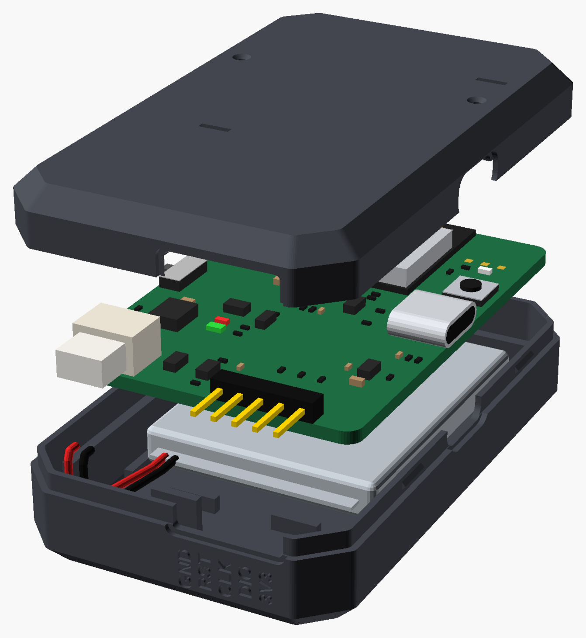
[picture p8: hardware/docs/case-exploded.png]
Explosionsansicht
|  | |

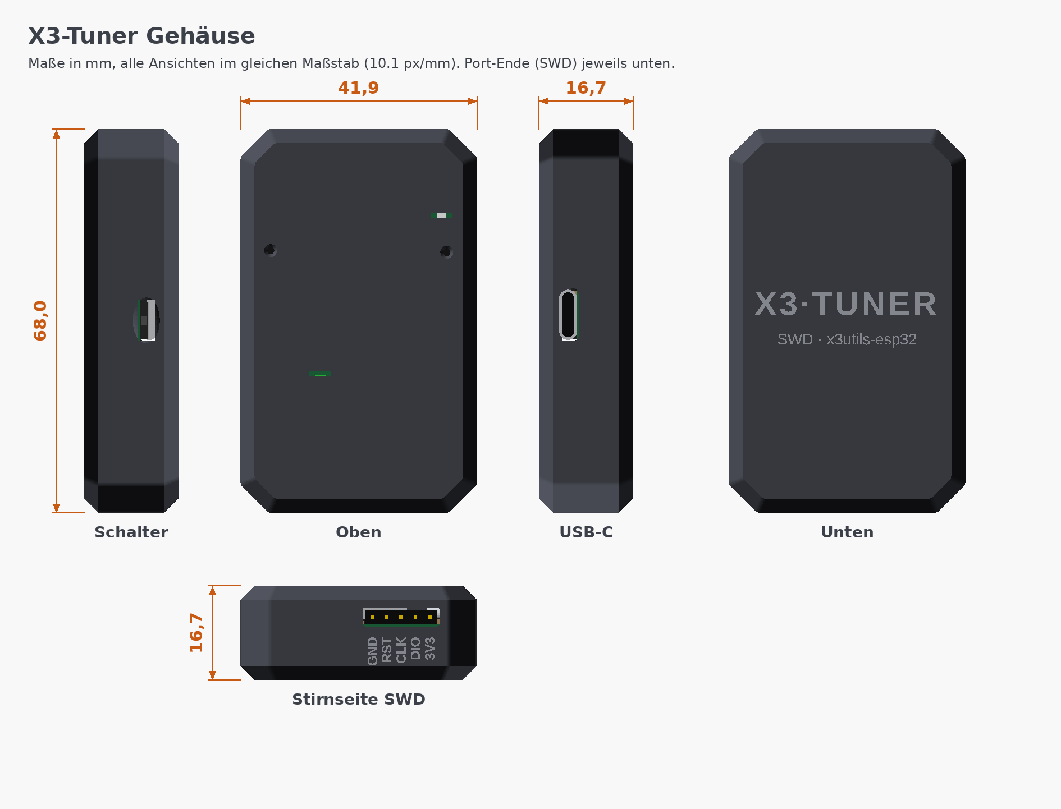
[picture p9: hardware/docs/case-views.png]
Ansichten mit Maßen


## Aufbau von unten nach oben

| Ebene | Höhe |
|---|---|
| Boden | 1,2 mm |
| 503040-LiPo im Fach mit Führungsstegen | 5,6 mm |
| Luft für Lötstellen und USB-C-Beinchen | 1,5 mm |
| Platine auf Auflageleisten, Bauteile oben | 1,6 mm |
| Platz für die Bauteile (höchstes Teil: JST-Buchse, 4,9 mm) | 5,4 mm |
| Deckel | 1,4 mm |
| **Gesamt** | **16,7 mm** |

Die Trennfuge liegt auf Höhe der Platinenoberseite. Der Rastrand der
Unterschale greift in den Deckel.

## Dateien

| Datei | Inhalt |
|---|---|
| `stl/x3tuner-case-bottom.stl` | Unterschale: Akkufach, Auflagen für die Platine, Rastrand, Logo-Gravur |
| `stl/x3tuner-case-lid.stl` | Deckel: Lichtschlitze, Pin-Löcher RESET/BOOT, Niederhalter |
| `stl/x3tuner-case-print.stl` | beide Teile druckfertig auf einer Platte (Deckel liegt kopfüber) |
| `x3tuner_case.scad` | parametrisches OpenSCAD-Modell |
| `board_data.scad` | Bauteilpositionen, automatisch aus `gen/circuit.py` und der KiCad-Platine erzeugt |

## Details

* **Akku:** Fach für einen **503040-LiPo** (30 × 40 × 5 mm, ca. 600 mAh) unter
  der Platine, Grundfläche bis 31,5 × 42 mm. Für andere Akkus
  `BAT = [Breite, Länge, Dicke]` in der `.scad` ändern und neu exportieren.
* **USB-C** rechts, **Ein/Aus-Schieber** links mit Griffmulde (jeweils mit
  dem SWD-Ende zu dir). Den Hebel des MSK12C02 schiebst du mit dem Fingernagel.
* **SWD-Port** an der Stirnseite: Ein 5-poliges Dupont-Buchsengehäuse wird
  durch den Schlitz auf die Stiftleiste gesteckt. Die Belegung
  (3V3, DIO, CLK, RST, GND) ist unter dem Schlitz eingraviert.
* **LEDs:** zwei offene Lichtschlitze (3,8 × 0,9 mm) im Deckel. Kleine
  Schächte darunter verhindern, dass sich das Licht im Gehäuse verteilt.
  Vorne links sitzt die Lade-LED (rot/grün), hinten rechts die Status-LED.
* **Tasten:** RESET und BOOT erreichst du durch zwei versenkte Pin-Löcher
  (1,3 mm) mit einer Büroklammer. Ein Führungsröhrchen lenkt sie auf den Taster.
  So drückt niemand aus Versehen.
* **Halt:** Der Deckel rastet mit vier Nasen ein, zwei je Längsseite. Vier
  Stifte im Deckel drücken die Platine auf ihre Auflagen. Schrauben braucht es nicht.
* **Unterseite:** eingraviertes Logo „X3·TUNER". Es ist lesbar, wenn du das
  Gerät über die Längsachse umdrehst.
* **Antenne:** Am Antennenende ist das Gehäuse 3 mm länger als die Platine.
  Dort liegt kein Metall in der Nähe des Moduls.

## Drucken

* PLA oder PETG, 0,2 mm Schichthöhe, 3 Wände, 15–20 % Infill, **ohne Stützen**.
  Alle Fasen haben 45°, das geht ohne Stützen.
* Unterschale mit dem Boden aufs Druckbett, **Deckel mit der Oberseite aufs Bett**.
  So liegt es schon in `print.stl`.
* Druckzeit ca. 1,5–2 h, ca. 13–16 g Material.
* Optional: die Gravuren (Logo, Pin-Namen) mit einem hellen Lackstift ausfüllen.
  In den Renderings ist das hellgrau angedeutet.

## Zusammenbau

Die Platine kommt fertig bestückt von JLC, inklusive Stiftleiste J3. Gelötet
wird nichts. Die Pin-Enden von J3 auf der Unterseite liegen neben dem Akkufach
und müssen nicht gekürzt werden.

1. Akku mit doppelseitigem Klebeband ins Fach legen, die Kabelseite zum SWD-Ende.
   Das Kabel läuft am Boden zum SWD-Ende und dort hinter der Platinenkante nach
   oben zum Stecker J2 (siehe Ansicht von unten).
2. Akku einstecken (**Polarität prüfen!**). Dann die Platine einlegen: Bauteile
   nach oben, Stiftleiste zum Schlitz.
3. Deckel aufsetzen und an allen vier Rastnasen einrasten lassen. Zum Öffnen die
   Längsseiten leicht auseinanderziehen.

## Anpassen

```bash
# nach Änderungen an Platine (circuit.py) oder Gehäuse:
hardware/gen/make_case.sh     # board_data.scad, STL-Dateien, alle Bilder
```

Wichtige Parameter oben in `x3tuner_case.scad`:

* `BAT` (Akkufach)
* `FACET` und `CORNER` (Größe der Fasen)
* `WALL`
* `FIT` (Passung des Rastrands, bei strammem Sitz auf 0,2 erhöhen)
* `TOP_CLEAR`, `PIN_HOLE`, `SLIT`

Die Vorschau-Teile wählst du mit `part`:

* `assembly`: geschlossen
* `xray`: durchsichtig
* `section`: Schnitt
* `exploded`: Explosionsansicht

Mit `-D USE_STL=true` laden diese Ansichten die fertigen STL-Dateien. Das ist
schneller und die Transparenz wird sauberer dargestellt.

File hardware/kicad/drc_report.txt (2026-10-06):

** Drc report for /home/user/x3utils-esp32/hardware/kicad/x3tuner.kicad_pcb **
** Created on 2026-10-06 15:19:54 **

** Found 0 DRC violations **

** Found 0 unconnected pads **

** Found 0 Footprint errors **

** End of Report **

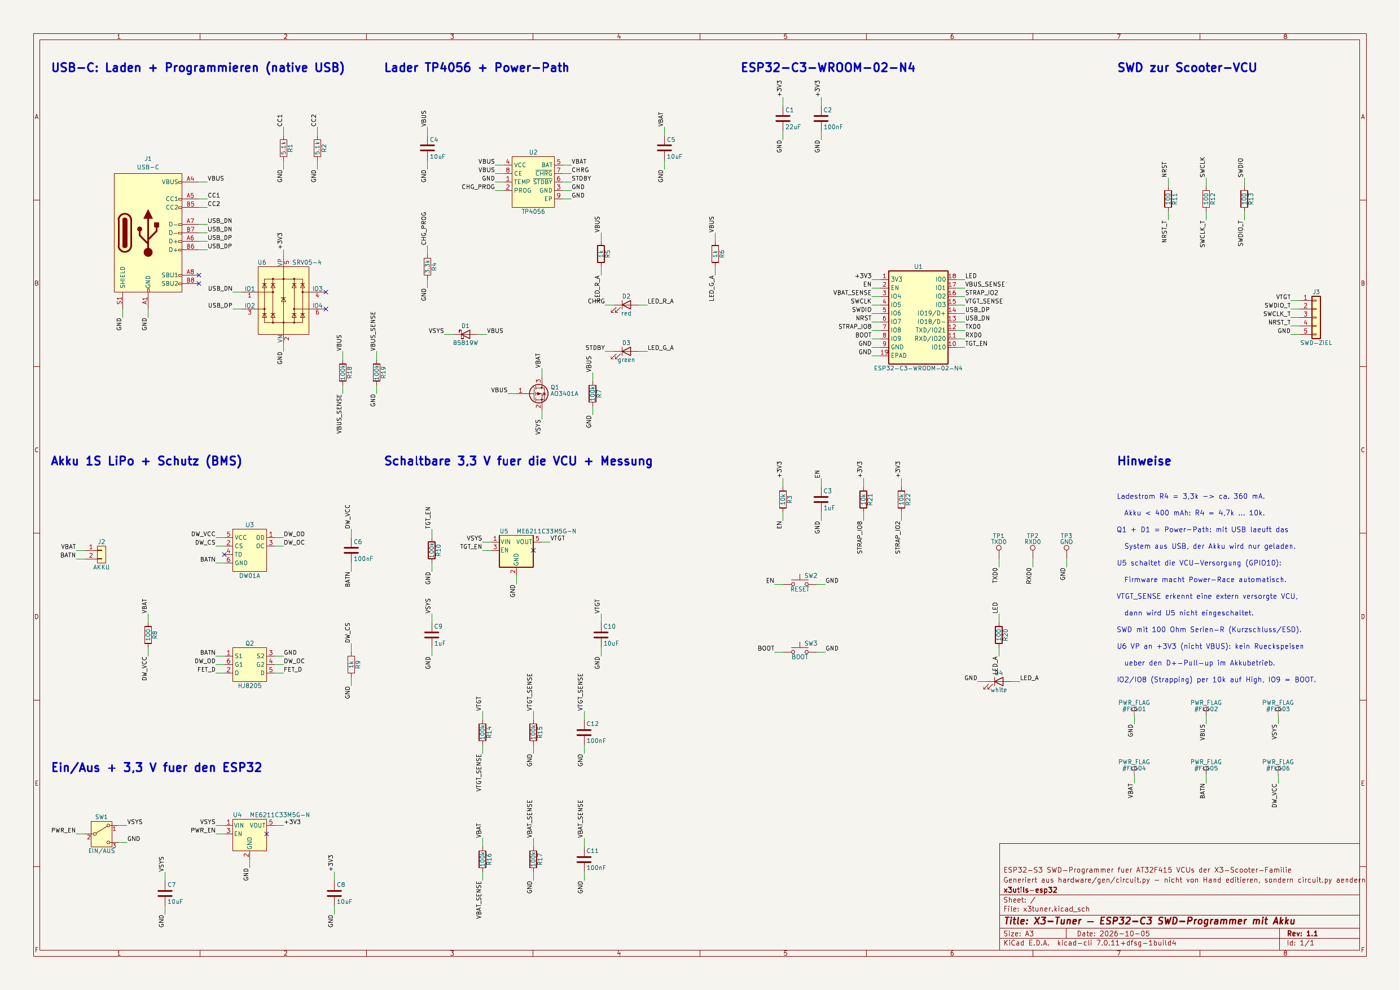
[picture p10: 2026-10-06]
hardware/docs/schematic.png

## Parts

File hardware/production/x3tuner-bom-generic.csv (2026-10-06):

Designator | Qty | Value | Package | Manufacturer | MPN | LCSC | Description
C1 | 1 | 22uF | C_0805_2012Metric |  |  | C45783 | MLCC X5R/X7R, >= 10 V
C2,C6,C11,C12 | 4 | 100nF | C_0402_1005Metric |  |  | C1525 | MLCC X5R/X7R, >= 10 V
C3,C9 | 2 | 1uF | C_0402_1005Metric |  |  | C52923 | MLCC X5R/X7R, >= 10 V
C4,C5,C7,C8,C10 | 5 | 10uF | C_0603_1608Metric |  |  | C19702 | MLCC X5R/X7R, >= 10 V
D1 | 1 | B5819W | D_SOD-123 | CJ | B5819W SL | C8598 | Power-Path USB → System
D2 | 1 | red | LED_0603_1608Metric | KENTO | KT-0603R | C2286 | LED rot = lädt
D3 | 1 | green | LED_0805_2012Metric |  |  | C2297 | LED grün = voll
D4 | 1 | white | LED_0603_1608Metric | KENTO | KT-0603W | C2290 | Status-LED weiß
J1 | 1 | USB-C | USB_C_Receptacle_HRO_TYPE-C-31-M-12 | HRO | TYPE-C-31-M-12 | C165948 | USB-C Buchse 16 Pin
J2 | 1 | AKKU | JST_PH_S2B-PH-SM4-TB_1x02-1MP_P2.00mm_Horizontal | JST | S2B-PH-SM4-TB(LF)(SN) | C295747 | LiPo 1S Anschluss JST-PH 2.0
J3 | 1 | SWD-ZIEL | PinHeader_1x05_P2.54mm_Horizontal | hanxia | HX PZ2.54-1x5P WZ (1x5 2.54 mm, gewinkelt, THT) | C32713264 | Stiftleiste 1x5 gewinkelt zum Scooter (3V3 DIO CLK RST GND)
Q1 | 1 | AO3401A | SOT-23 | AOS | AO3401A | C15127 | Power-Path Akku → System (P-MOSFET)
Q2 | 1 | HJ8205 | SOT-23-6 | HJ | HJ8205 (alt. FS8205A SOT-23-6, same pinout) | C20069150 | Dual N-MOSFET Akku-Schutz
R1,R2 | 2 | 5.1k | R_0402_1005Metric |  |  | C25905 | Widerstand 1 %, Dickschicht
R3,R21,R22 | 3 | 10k | R_0402_1005Metric |  |  | C25744 | Widerstand 1 %, Dickschicht
R4 | 1 | 3.3k | R_0402_1005Metric |  |  | C25890 | Widerstand 1 %, Dickschicht
R5,R6,R9 | 3 | 1k | R_0402_1005Metric |  |  | C11702 | Widerstand 1 %, Dickschicht
R7,R10,R14,R15,R16,R17,R18,R19 | 8 | 100k | R_0402_1005Metric |  |  | C25741 | Widerstand 1 %, Dickschicht
R8,R11,R12,R13,R20 | 5 | 100 | R_0402_1005Metric |  |  | C25076 | Widerstand 1 %, Dickschicht
SW1 | 1 | EIN/AUS | SW_SPDT_MSK12C02 | SHOU HAN | MSK12C02 | C431540 | Schiebeschalter Ein/Aus
SW2 | 1 | RESET | SW_Push_1P1T_XKB_TS-1187A | XKB | TS-1187A-B-A-B | C318884 | Taster RESET
SW3 | 1 | BOOT | SW_Push_1P1T_XKB_TS-1187A | XKB | TS-1187A-B-A-B | C318884 | Taster BOOT / Funktion
U1 | 1 | ESP32-C3-WROOM-02-N4 | ESP32-C3-WROOM-02_JLC | Espressif | ESP32-C3-WROOM-02-N4 | C2934560 | ESP32-C3, 4 MB Flash, 400 KB SRAM, WiFi + BLE
U2 | 1 | TP4056 | SOIC-8-1EP_3.9x4.9mm_P1.27mm_EP2.41x3.3mm | TOPPOWER | TP4056-42-ESOP8 | C16581 | Li-Ion Lader 1S, ~360 mA
U3 | 1 | DW01A | SOT-23-6 | PUOLOP | DW01A | C351410 | Akku-Schutz IC
U4,U5 | 2 | ME6211C33M5G-N | SOT-23-5 | Microne | ME6211C33M5G-N | C82942 | LDO 3,3 V ESP32 (500 mA)
U6 | 1 | SRV05-4 | SOT-23-6 | TECH PUBLIC | SRV05-4 (alt. ProTek SRV05-4-P-T7, same pinout) | C558418 | USB ESD-Schutz

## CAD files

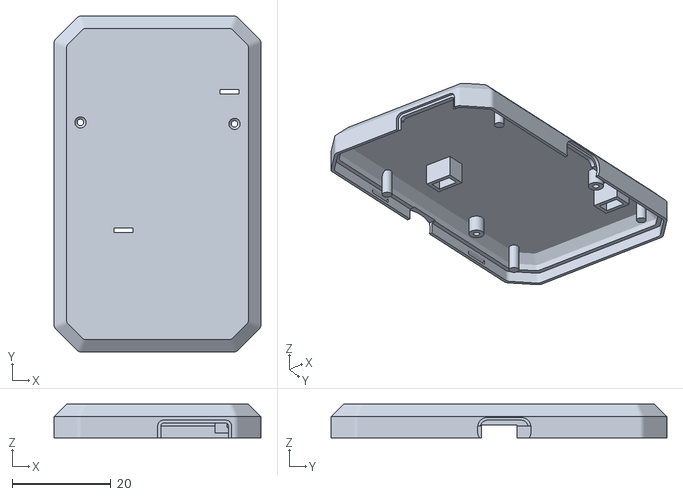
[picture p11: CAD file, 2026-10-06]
hardware/case/stl/x3tuner-case-lid.stl
41.9 x 68.0 x 6.80

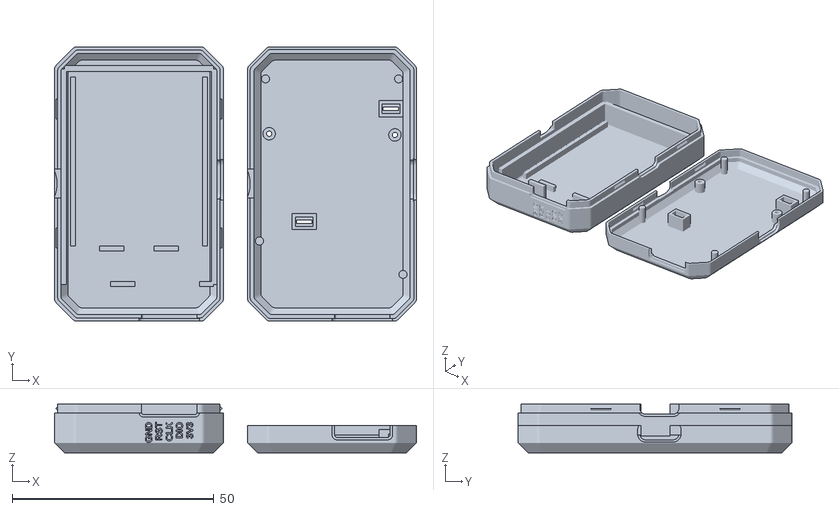
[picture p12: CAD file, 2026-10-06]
hardware/case/stl/x3tuner-case-print.stl
89.8 x 68.0 x 12.1

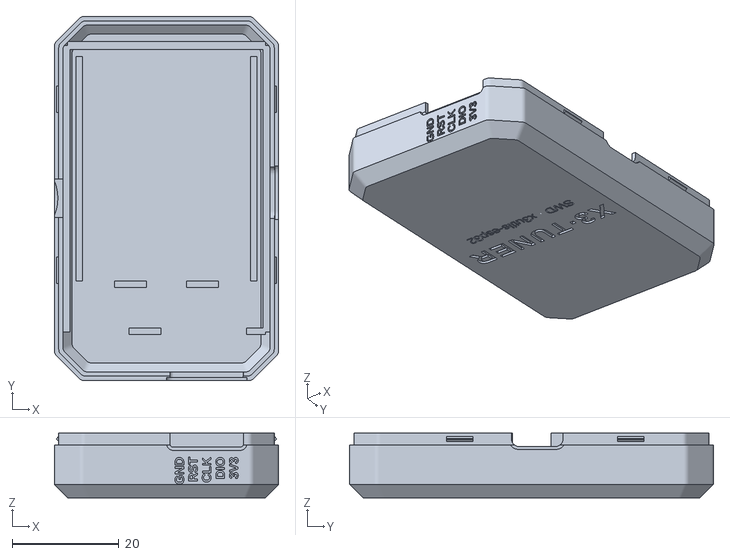
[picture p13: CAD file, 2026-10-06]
hardware/case/stl/x3tuner-case-bottom.stl
41.9 x 68.0 x 12.1

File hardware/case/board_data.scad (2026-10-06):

// GENERATED by hardware/gen/make_case_data.py from circuit.py — do not edit.
BOARD_W = 38.0;
BOARD_H = 54.5;
BOARD_R = 2.0;
PCB_T = 1.6;
U1_XY = [19.0, 40.8];
ANTENNA_Y = 47.9;  // above this Y: antenna, keep metal away
MODULE_BOTTOM_Y = 33.9;
USB_Y = 26.5;
USB_RIGHT = true;
USB_FRONT_X = 38.3;
SW1_Y = 25.5;
SW1_RIGHT = false;
SW1_LEVER_X = -0.95;
J2_XY = [6.0, 5.0];
J2_FRONT_Y = 0.6;
J3_PIN1_X = 31.6;
J3_ROW_Y = 4.04;
J3_TIP_Y = -6.0;  // pin tips (10.04 mm from the pin row)
J3_PITCH = 2.54;
J3_LABELS = ["3V3", "DIO", "CLK", "RST", "GND"];
SW2_XY = [34.6, 37.6];  // RESET
SW3_XY = [3.4, 37.9];  // BOOT
LED_STAT_XY = [33.6, 44.1];
LED_CHG_XY = [12.1, 16.1];  // red + green, one window
LID_POSTS = [[2.5, 51.5], [35.5, 51.5], [36.6, 3.0], [1.0, 11.3]];
// small parts for the preview renders: [x0, y0, w, h, height, colour]
PARTS = [
  [1.13, 15.08, 0.54, 1.05, 0.35, "#1b1b1b"],
  [10.60, 19.70, 2.80, 1.80, 1.1, "#2b2b2b"],
  [11.20, 14.60, 2.00, 1.20, 0.6, "#30e040"],
  [11.20, 16.60, 1.60, 0.80, 0.6, "#ff3030"],
  [12.00, 3.55, 1.60, 2.90, 1.1, "#2b2b2b"],
  [12.20, 29.20, 0.80, 1.60, 0.8, "#b8946a"],
  [14.58, 14.93, 1.05, 0.54, 0.35, "#1b1b1b"],
  [14.58, 16.73, 1.05, 0.54, 0.35, "#1b1b1b"],
  [14.60, 28.55, 1.60, 2.90, 1.1, "#2b2b2b"],
  [15.88, 21.53, 1.05, 0.54, 0.35, "#1b1b1b"],
  [15.95, 17.75, 1.30, 2.90, 1.1, "#2b2b2b"],
  [16.20, 3.55, 1.60, 2.90, 1.1, "#2b2b2b"],
  [16.47, 1.93, 1.05, 0.54, 0.35, "#1b1b1b"],
  [16.47, 8.13, 1.05, 0.54, 0.35, "#1b1b1b"],
  [17.80, 29.20, 0.80, 1.60, 0.8, "#b8946a"],
  [18.33, 24.38, 0.54, 1.05, 0.35, "#1b1b1b"],
  [19.35, 7.30, 0.50, 1.00, 0.5, "#b8946a"],
  [19.53, 24.38, 0.54, 1.05, 0.35, "#1b1b1b"],
  [20.75, 24.40, 0.50, 1.00, 0.5, "#b8946a"],
  [23.20, 26.15, 1.60, 2.90, 1.1, "#2b2b2b"],
  [23.71, 8.88, 0.54, 1.05, 0.35, "#1b1b1b"],
  [24.08, 30.73, 1.05, 0.54, 0.35, "#1b1b1b"],
  [24.08, 31.83, 1.05, 0.54, 0.35, "#1b1b1b"],
  [26.25, 8.88, 0.54, 1.05, 0.35, "#1b1b1b"],
  [26.58, 24.33, 1.05, 0.54, 0.35, "#1b1b1b"],
  [26.58, 27.98, 1.05, 0.54, 0.35, "#1b1b1b"],
  [28.79, 8.88, 0.54, 1.05, 0.35, "#1b1b1b"],
  [29.53, 41.57, 0.54, 1.05, 0.35, "#1b1b1b"],
  [29.95, 45.95, 0.90, 0.90, 0.05, "#d4af37"],
  [3.08, 45.33, 1.05, 0.54, 0.35, "#1b1b1b"],
  [3.10, 44.15, 1.00, 0.50, 0.5, "#b8946a"],
  [30.15, 12.90, 0.50, 1.00, 0.5, "#b8946a"],
  [30.48, 43.83, 1.05, 0.54, 0.35, "#1b1b1b"],
  [32.15, 45.95, 0.90, 0.90, 0.05, "#d4af37"],
  [32.20, 10.00, 1.60, 0.80, 0.8, "#b8946a"],
  [32.20, 11.95, 1.60, 2.90, 1.1, "#2b2b2b"],
  [32.80, 43.70, 1.60, 0.80, 0.6, "#ffffff"],
  [33.95, 18.20, 0.50, 1.00, 0.5, "#b8946a"],
  [34.35, 45.95, 0.90, 0.90, 0.05, "#d4af37"],
  [35.13, 18.18, 0.54, 1.05, 0.35, "#1b1b1b"],
  [35.33, 12.88, 0.54, 1.05, 0.35, "#1b1b1b"],
  [36.33, 18.18, 0.54, 1.05, 0.35, "#1b1b1b"],
  [4.65, 12.55, 3.90, 4.90, 1.6, "#2b2b2b"],
  [5.20, 10.80, 1.60, 0.80, 0.8, "#b8946a"],
  [5.20, 19.00, 1.60, 0.80, 0.8, "#b8946a"],
  [5.77, 44.80, 1.25, 2.00, 1.0, "#b8946a"],
  [7.33, 37.27, 0.54, 1.05, 0.35, "#1b1b1b"],
  [8.25, 44.80, 0.50, 1.00, 0.5, "#b8946a"]
];

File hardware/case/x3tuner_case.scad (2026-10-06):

// X3-Tuner case — faceted "stick" style, two-part snap-fit, PCB + 1S LiPo.
//
// Design language: flat top and bottom, 45 degree facets along every edge
// (octagonal cross-section, chamfered corners in plan view), small radius on
// the plan corners, matte black. Light slits instead of visible LEDs, recessed
// pin-holes for RESET/BOOT, USB-C and the power slider on the long sides, the
// SWD port in the end face.
//
//   part = "bottom" | "lid"     single parts (STL)
//   part = "print"              both parts laid out for printing (lid upside down)
//   part = "assembly"           closed device (opaque, internals visible through the openings)
//   part = "xray"               see-through shell showing PCB and battery
//   part = "exploded"           exploded view
//   part = "section"            cutaway along the length (layer stack)
//
// All board-related positions come from board_data.scad, which
// hardware/gen/make_case_data.py generates from hardware/gen/circuit.py.
// Print: PLA/PETG (matte black looks best), 0.2 mm layers, no supports,
// bottom shell on its floor, lid with its top face on the bed.

include <board_data.scad>

part = "assembly";

/* [Battery] */
// Pocket for a 503040 LiPo (30 x 40 x 5 mm nominal, ~600 mAh) incl. margin.
BAT = [31.5, 42.0, 5.6];

/* [Shell] */
WALL = 1.6;       // side walls
FLOOR = 1.2;      // bottom thickness
LID = 1.4;        // top thickness
GAP = 0.35;       // PCB edge to inner wall
BAT_GAP = 1.5;    // battery top to PCB underside (THT tails, USB-C shell legs)
TOP_CLEAR = 5.4;  // PCB top to lid underside (tallest part: JST-PH, ~4.9 mm)
END_EXT = 7.0;    // room behind the SWD edge: header pins + battery plug
ANT_EXT = 3.0;    // extra room at the antenna end (lets the corner facets clear the PCB)
FACET = 2.5;      // 45 degree facet along the top and bottom edges
CORNER = 5.0;     // 45 degree corner facet in plan view
ROUND = 1.2;      // plan-view rounding of the facet edges
LIP_T = 0.8;      // snap lip thickness
LIP_H = 2.2;      // snap lip height
FIT = 0.15;       // print clearance lip <-> skirt
BTN_H = 1.5;      // tactile switch height (TS-1187A)
PIN_HOLE = 1.3;   // RESET/BOOT pin-hole diameter (paper clip)
SLIT = [3.8, 0.9];  // LED light slit (x, y)

$fn = 40;

Z_PCB_BOT = FLOOR + BAT[2] + BAT_GAP;
Z_PCB_TOP = Z_PCB_BOT + PCB_T;
H = Z_PCB_TOP + TOP_CLEAR + LID;
Z_SPLIT = Z_PCB_TOP;
Z_LID_IN = H - LID;
FACET_IN = FACET - 0.8;  // keeps ~1.4 mm wall across the facets

IN = [-GAP, -END_EXT, BOARD_W + GAP, BOARD_H + GAP + ANT_EXT];   // x0 y0 x1 y1
OUT = [IN[0] - WALL, IN[1] - WALL, IN[2] + WALL, IN[3] + WALL];

// ── geometry helpers ────────────────────────────────────────────────────────
module chamfer_rect(b, c) {
  polygon([[b[0] + c, b[1]], [b[2] - c, b[1]], [b[2], b[1] + c], [b[2], b[3] - c],
           [b[2] - c, b[3]], [b[0] + c, b[3]], [b[0], b[3] - c], [b[0], b[1] + c]]);
}
// Plan outline of the shell, grown/shrunk by d (negative = inside).
module plan(d = 0) {
  offset(r = ROUND) offset(delta = -ROUND) offset(delta = d) chamfer_rect(OUT, CORNER);
}
// Faceted solid: plan(d) between z0..z1 with 45 degree facets cb (bottom), ct (top).
module facet_body(d, z0, z1, cb, ct) {
  hull() {
    translate([0, 0, z0]) linear_extrude(0.01) plan(d - cb);
    translate([0, 0, z0 + cb]) linear_extrude(z1 - z0 - cb - ct) plan(d);
    translate([0, 0, z1 - 0.01]) linear_extrude(0.01) plan(d - ct);
  }
}
module shell_solid() { facet_body(0, 0, H, FACET, FACET); }
module cavity() { facet_body(-WALL, FLOOR, Z_LID_IN, FACET_IN, FACET_IN); }

module rbox(c, s, r) {  // centred rounded box
  translate(c) hull() for (x = [-s[0] / 2 + r, s[0] / 2 - r], y = [-s[1] / 2 + r, s[1] / 2 - r])
    translate([x, y, -s[2] / 2]) cylinder(r = r, h = s[2]);
}

// ── openings through the shell ──────────────────────────────────────────────
module ports() {
  // USB-C on whichever long side the board puts it
  usb_out = USB_RIGHT ? OUT[2] : OUT[0];
  translate([usb_out, USB_Y, Z_PCB_TOP + 1.63]) rotate([0, USB_RIGHT ? -90 : 90, 0]) {
    rbox([0, 0, (WALL + 1.2) / 2 - 1], [3.9, 9.7, WALL + 1.2 + 1], 1.5);
    rbox([0, 0, 0.1], [5.0, 10.8, 1.2], 2.0);  // soft lead-in on the outside
  }
  // power slider: slot + finger scoop
  sw_out = SW1_RIGHT ? OUT[2] : OUT[0];
  dir = SW1_RIGHT ? 1 : -1;
  translate([SW1_RIGHT ? IN[2] - 0.5 : OUT[0] - 1, SW1_Y - 3.6, Z_PCB_TOP - 0.4])
    cube([WALL + 1.5, 7.2, 3.0]);
  translate([sw_out + dir * 2.4, SW1_Y, Z_PCB_TOP + 1.1]) scale([1, 1.7, 1]) sphere(r = 3.4);
  // SWD port in the end face: a 5-pin Dupont housing slides over the pins
  pins_c = J3_PIN1_X - 2 * J3_PITCH;
  translate([pins_c, OUT[1] - 1, Z_PCB_TOP + 1.27]) rotate([-90, 0, 0]) {
    rbox([0, 0, (WALL + 1.2) / 2], [13.7, 3.4, WALL + 1.2 + 1], 0.6);
    rbox([0, 0, 0.8], [15.0, 4.6, 1.6], 1.2);
  }
}

// engraving depth on visible faces
ENGRAVE = 0.45;
// The cut-outs reach from `from` (mm under the surface) out through the face;
// the previews reuse them with a thin depth as a light "ink" in the engraving.
module end_face_labels(from = ENGRAVE - 0.01, depth = ENGRAVE + 1) {  // pin names under the SWD slot
  for (i = [0:4]) translate([J3_PIN1_X - i * J3_PITCH, OUT[1] + from, Z_PCB_TOP - 2.3])
    rotate([90, 0, 0]) linear_extrude(depth) rotate(90)
      text(J3_LABELS[i], size = 1.7, font = "Liberation Sans:style=Bold", halign = "right", valign = "center");
}
module bottom_logo(from = ENGRAVE - 0.01, depth = ENGRAVE) {  // readable when the device is turned over
  translate([BOARD_W / 2, (IN[1] + IN[3]) / 2, from - depth]) linear_extrude(depth) mirror([1, 0, 0]) {
    translate([0, 3]) text("X3·TUNER", size = 4.2, font = "Liberation Sans:style=Bold",
                          halign = "center", valign = "center", spacing = 1.15);
    translate([0, -3.5]) text("SWD · x3utils-esp32", size = 2.0, font = "Liberation Sans",
                             halign = "center", valign = "center");
  }
}
module engraving_ink() { color("#a9aeb6") { end_face_labels(ENGRAVE - 0.01, 0.15); bottom_logo(ENGRAVE - 0.01, 0.15); } }

// ── bottom shell ────────────────────────────────────────────────────────────
module lip_ring(extra = 0) { difference() { plan(-WALL + LIP_T + extra); plan(-WALL); } }
SNAPS = [[IN[0], 12], [IN[0], 44], [IN[2], 12], [IN[2], 44]];
module snap(s, grow = 0) {  // wedge bump on the lip; grow > 0 = matching groove
  dir = s[0] < 1 ? -1 : 1;
  x0 = s[0] + dir * (LIP_T - 0.1);
  z = Z_SPLIT + LIP_H / 2;
  hull() {
    translate([min(x0, x0 + dir * 0.01), s[1] - 2.5 - grow, z - 0.6 - grow]) cube([0.01, 5 + 2 * grow, 1.2 + 2 * grow]);
    translate([x0 + dir * (0.55 + grow) - 0.005, s[1] - 2.5 - grow, z - 0.05 - grow / 2]) cube([0.01, 5 + 2 * grow, 0.1 + grow]);
  }
}

module bottom() {
  intersection() {
    shell_solid();  // everything stays inside the faceted envelope
    difference() {
      union() {
        intersection() {
          shell_solid();
          translate([OUT[0] - 1, OUT[1] - 1, -1]) cube([OUT[2] - OUT[0] + 2, OUT[3] - OUT[1] + 2, Z_SPLIT + 1]);
        }
        translate([0, 0, Z_SPLIT - 0.01]) linear_extrude(LIP_H) lip_ring();
        for (s = SNAPS) snap(s);
        // PCB supports: side strips, antenna-end strip, two blocks at the port end
        for (b = [[IN[0] - 0.3, 0.5, 1.0, BOARD_H - 0.5], [BOARD_W - 1.0, 0.5, IN[2] + 0.3, BOARD_H - 0.5],
                  [0.5, BOARD_H - 1.2, BOARD_W - 0.5, BOARD_H + 0.3], [12, 0, 18, 1.2], [34, 0, 37.5, 1.2]])
          translate([b[0], b[1], FLOOR - 0.5]) cube([b[2] - b[0], b[3] - b[1], Z_PCB_BOT - FLOOR + 0.5]);
        // battery fences
        bx0 = (BOARD_W - BAT[0]) / 2;
        by0 = BOARD_H - 2.5 - BAT[1];
        for (f = [[bx0 - 1.2, by0, 1.2, BAT[1]], [bx0 + BAT[0], by0, 1.2, BAT[1]],
                  [bx0 + 6, by0 - 1.2, 6, 1.2], [bx0 + BAT[0] - 12, by0 - 1.2, 6, 1.2]])
          translate([f[0], f[1], FLOOR - 0.5]) cube([f[2], f[3], 2.5]);
      }
      cavity_minus_supports();
      ports();
      end_face_labels();
      bottom_logo();
    }
  }
}
// The cavity is cut first, then supports/fences are added back on top of it.
module cavity_minus_supports() {
  difference() {
    cavity();
    for (b = [[IN[0] - 0.3, 0.5, 1.0, BOARD_H - 0.5], [BOARD_W - 1.0, 0.5, IN[2] + 0.3, BOARD_H - 0.5],
              [0.5, BOARD_H - 1.2, BOARD_W - 0.5, BOARD_H + 0.3], [12, 0, 18, 1.2], [34, 0, 37.5, 1.2]])
      translate([b[0], b[1], FLOOR - 0.6]) cube([b[2] - b[0], b[3] - b[1], Z_PCB_BOT - FLOOR + 0.6]);
    bx0 = (BOARD_W - BAT[0]) / 2;
    by0 = BOARD_H - 2.5 - BAT[1];
    for (f = [[bx0 - 1.2, by0, 1.2, BAT[1]], [bx0 + BAT[0], by0, 1.2, BAT[1]],
              [bx0 + 6, by0 - 1.2, 6, 1.2], [bx0 + BAT[0] - 12, by0 - 1.2, 6, 1.2]])
      translate([f[0], f[1], FLOOR - 0.6]) cube([f[2], f[3], 2.6]);
  }
}
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

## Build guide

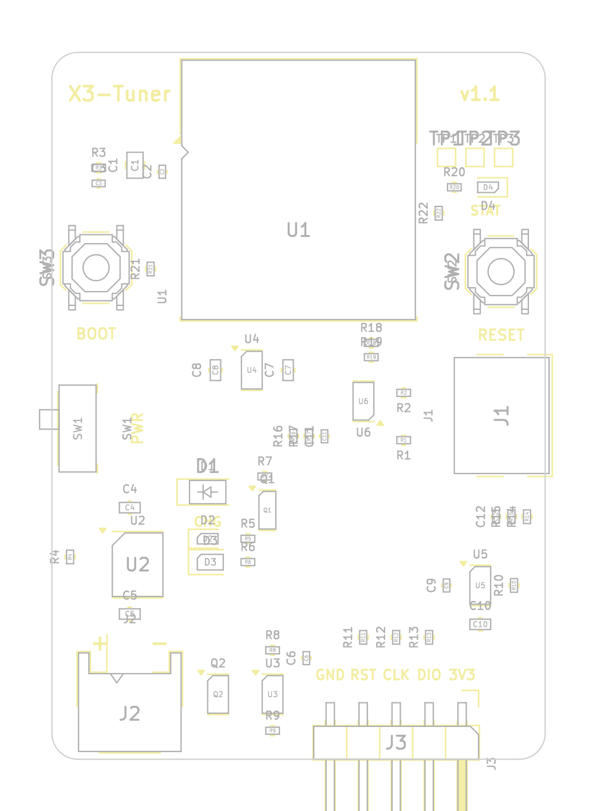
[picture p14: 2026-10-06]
hardware/docs/pcb-assembly.png

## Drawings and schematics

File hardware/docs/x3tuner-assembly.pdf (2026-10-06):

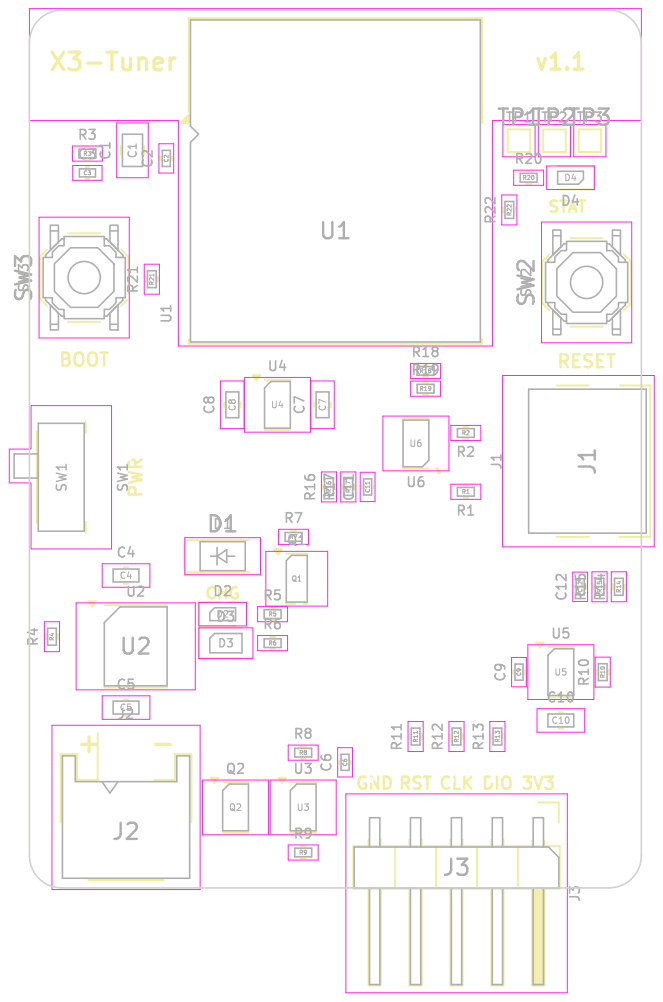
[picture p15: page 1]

GND RST PWR + X3-Tuner

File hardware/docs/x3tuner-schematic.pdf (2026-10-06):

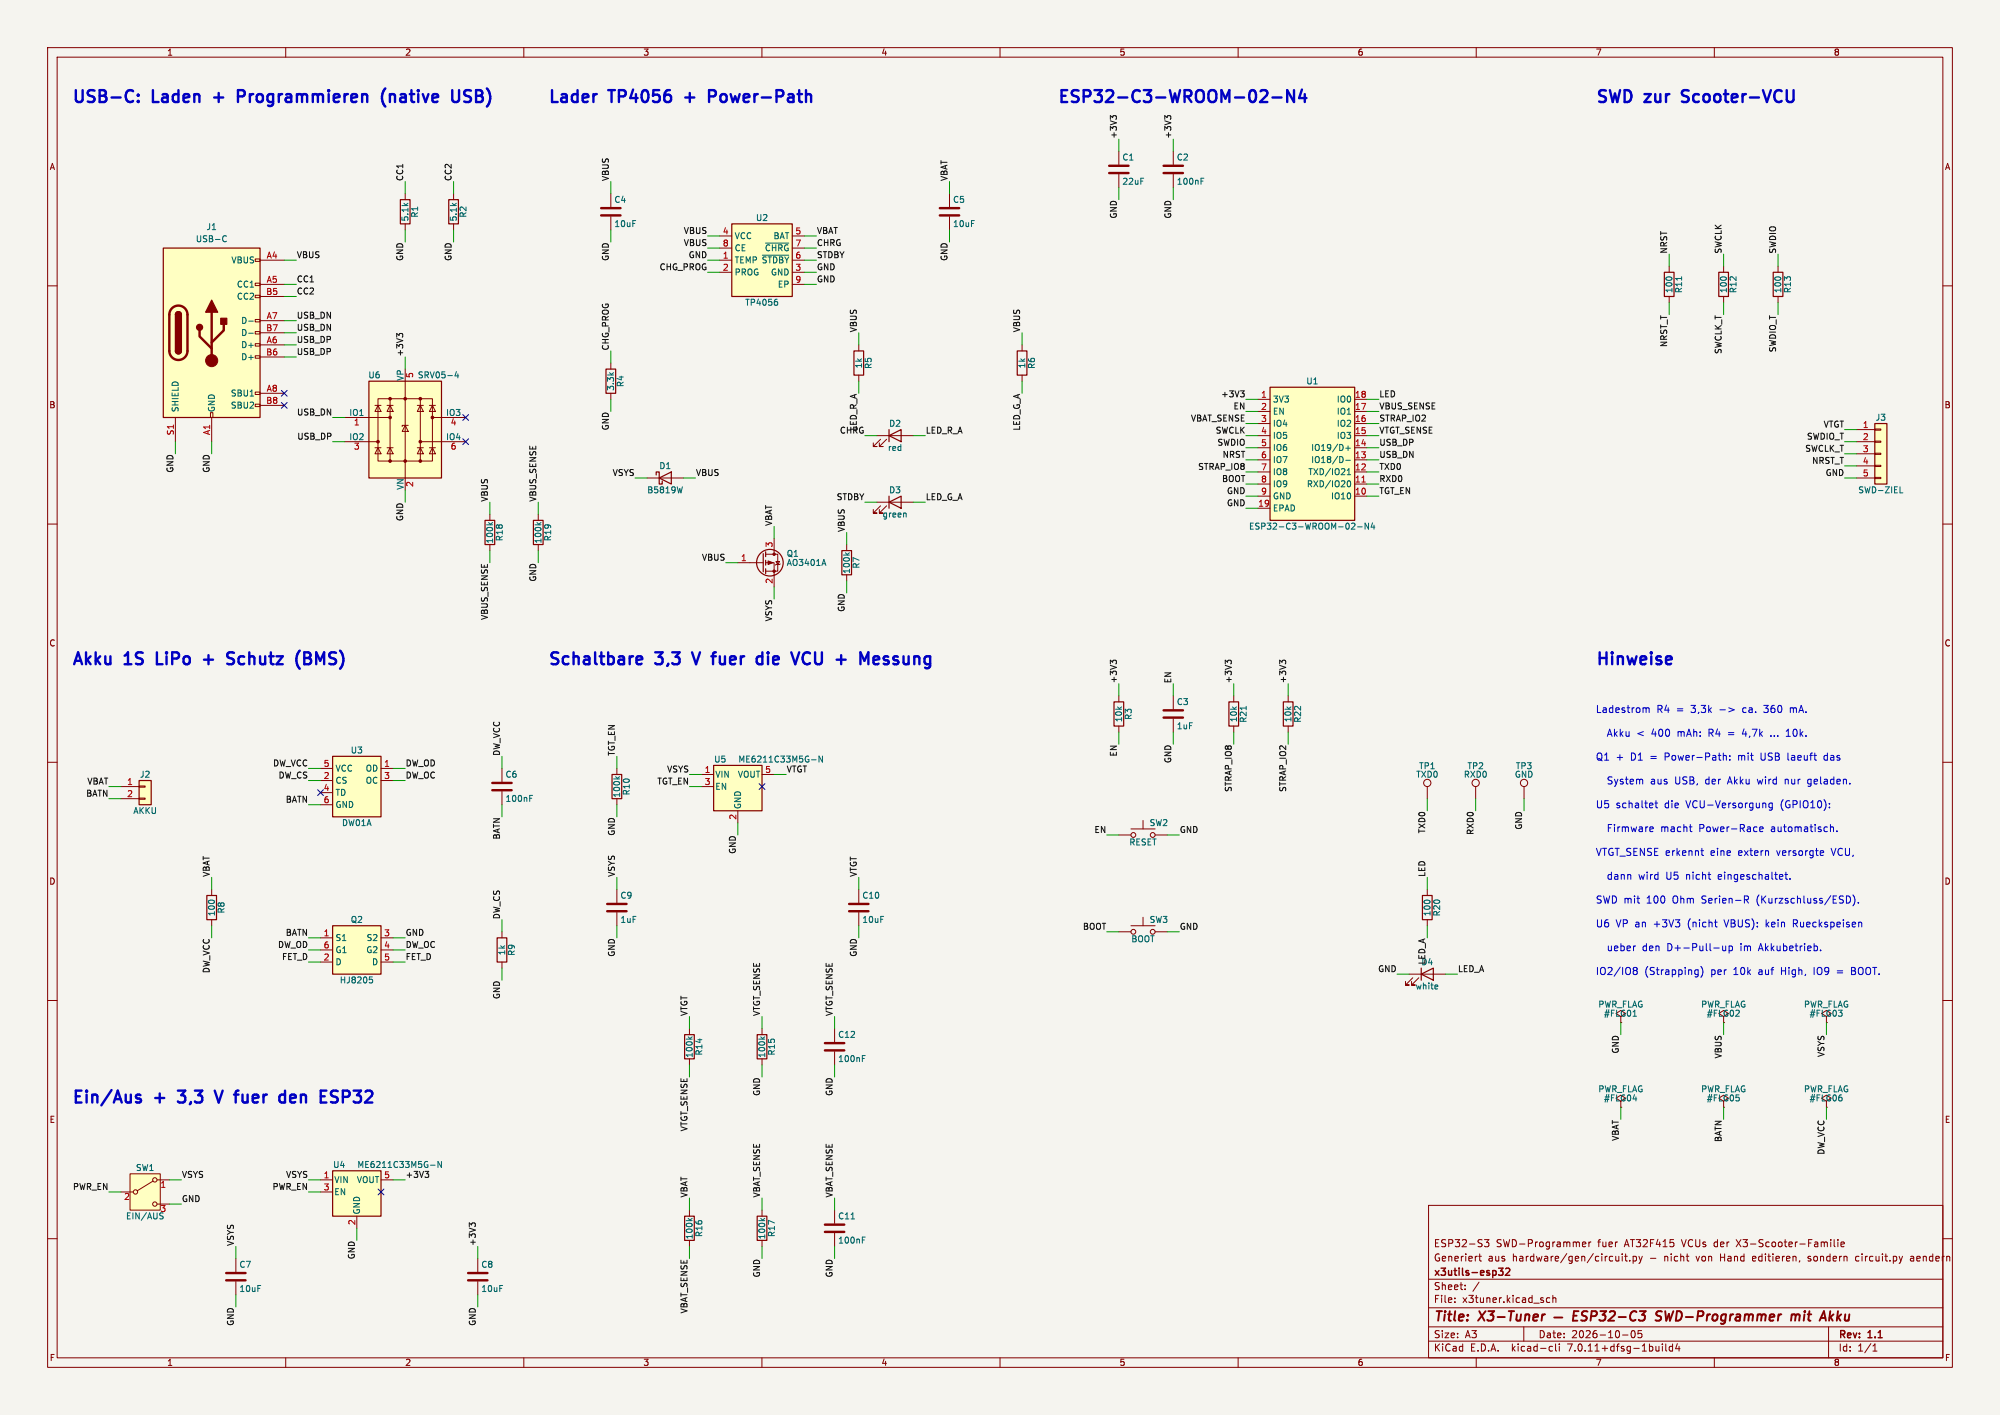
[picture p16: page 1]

Ein/Aus + 3,3 V fuer den ESP32

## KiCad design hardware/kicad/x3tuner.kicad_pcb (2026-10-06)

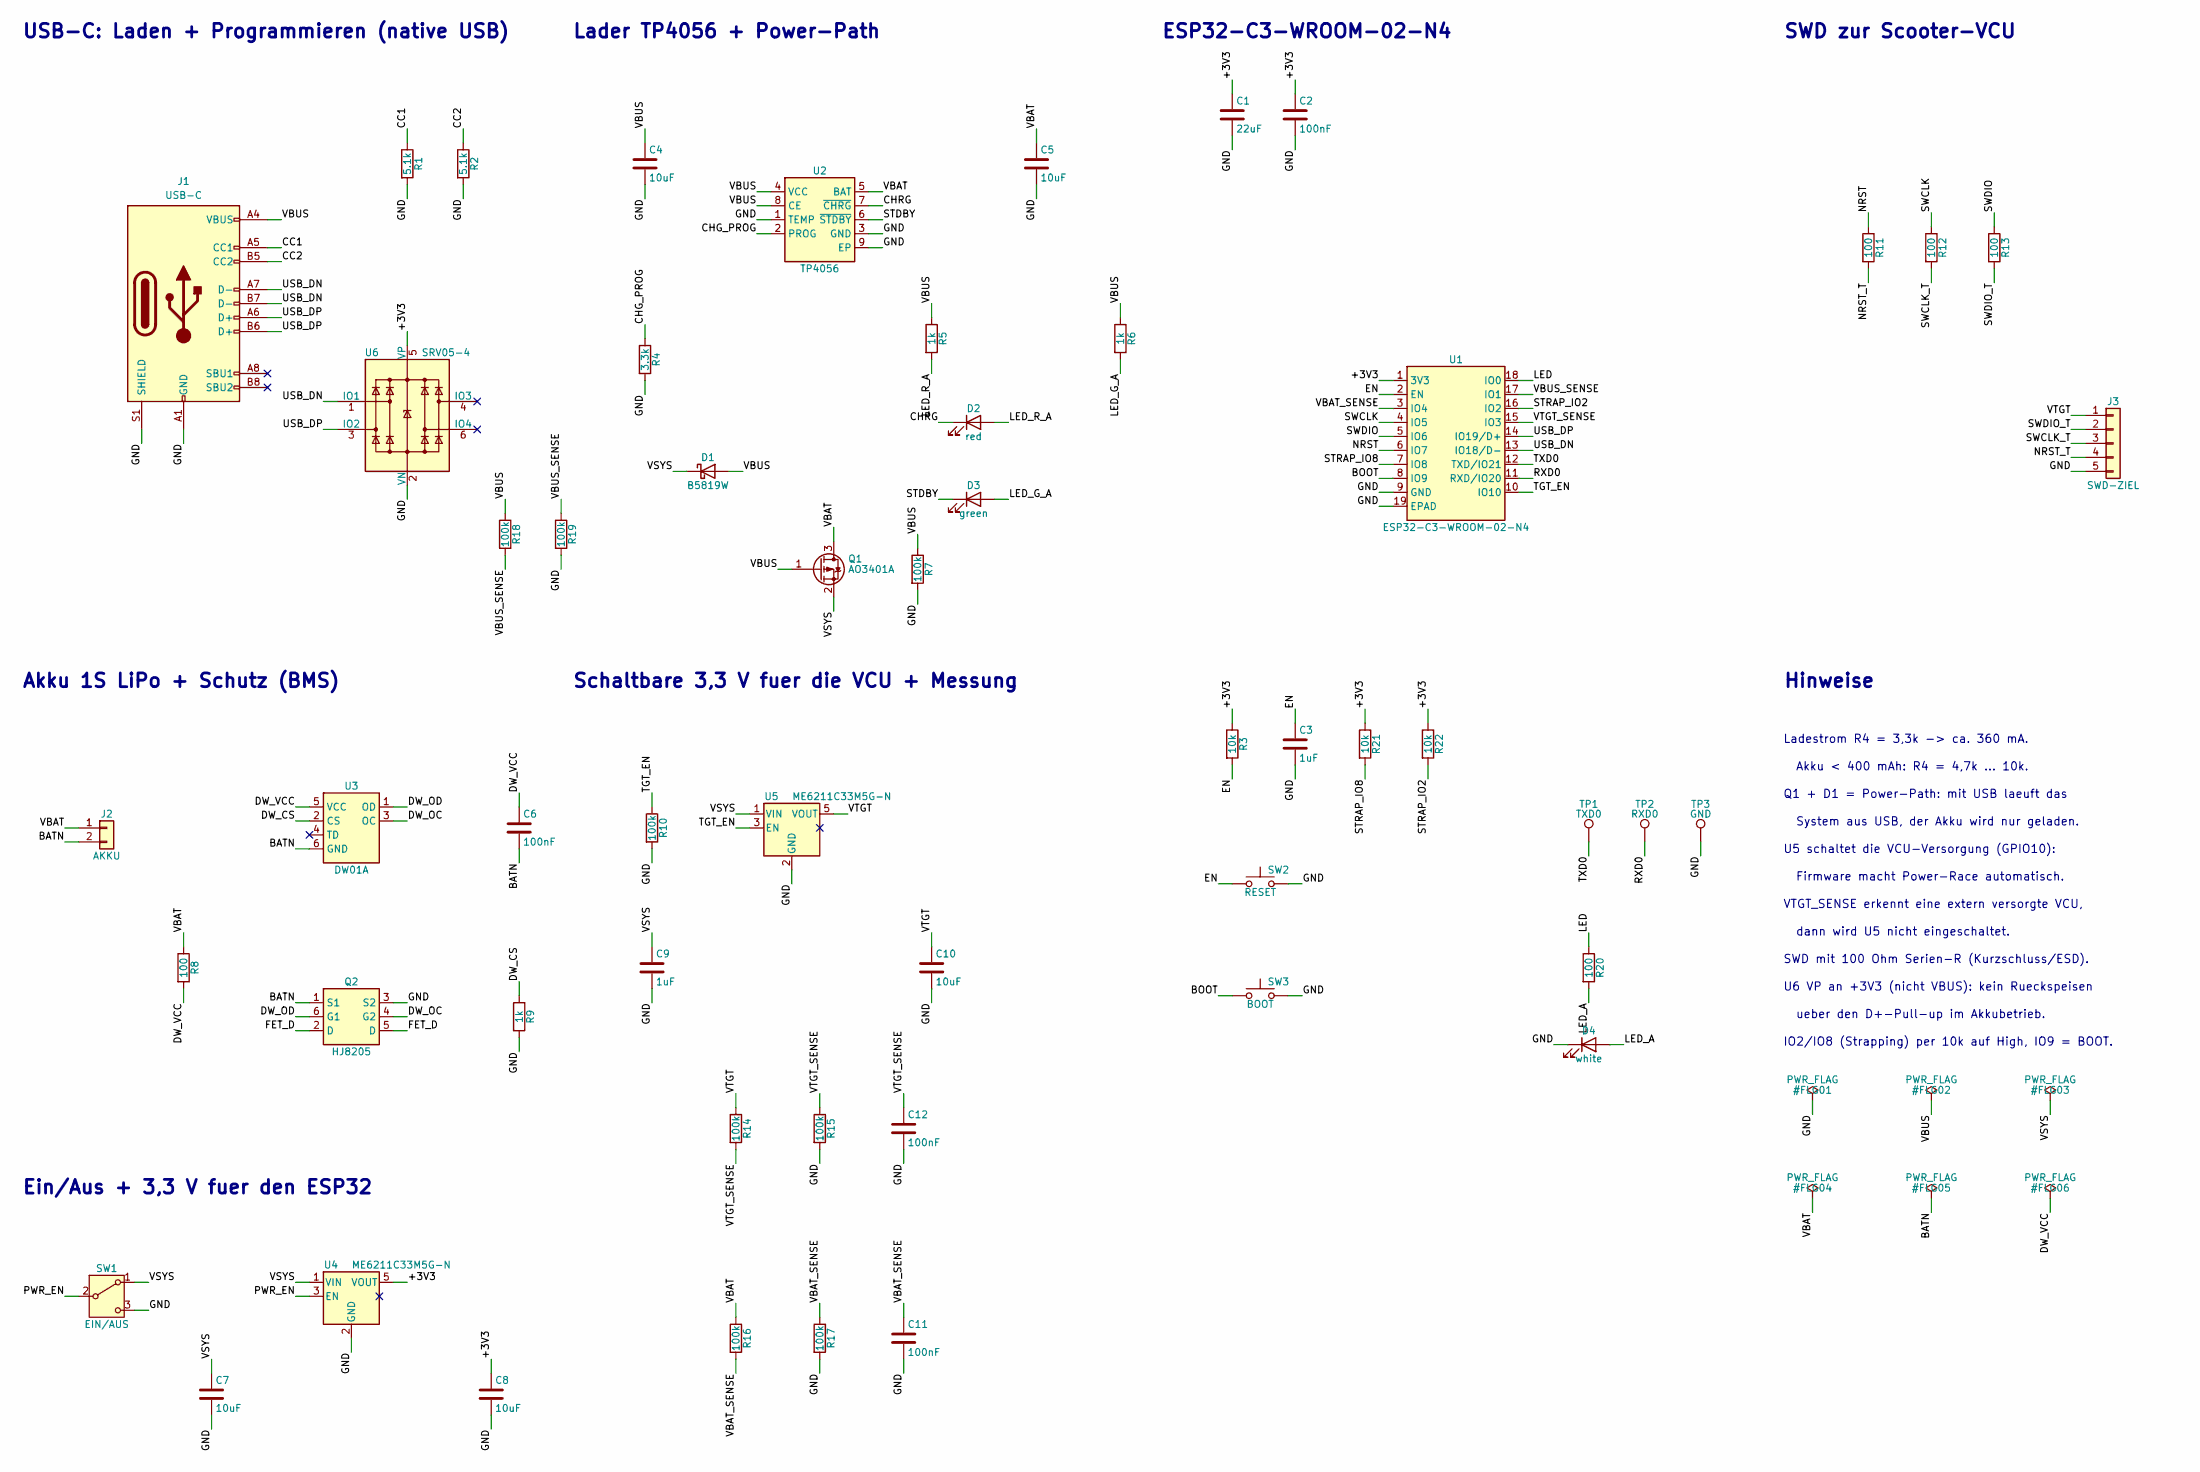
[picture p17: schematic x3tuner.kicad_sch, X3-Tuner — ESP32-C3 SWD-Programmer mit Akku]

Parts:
C1: 22uF; C_0805_2012Metric; LCSC C45783
C2, C6, C11, C12: 100nF; C_0402_1005Metric; LCSC C1525
C3, C9: 1uF; C_0402_1005Metric; LCSC C52923
C4, C5, C7, C8, C10: 10uF; C_0603_1608Metric; LCSC C19702
D1: B5819W; D_SOD-123; LCSC C8598
D2: red; LED_0603_1608Metric; LCSC C2286
D3: green; LED_0805_2012Metric; LCSC C2297
D4: white; LED_0603_1608Metric; LCSC C2290
J1: USB-C; USB_C_Receptacle_HRO_TYPE-C-31-M-12; LCSC C165948
J2: AKKU; JST_PH_S2B-PH-SM4-TB_1x02-1MP_P2.00mm_Horizontal; LCSC C295747
J3: SWD-ZIEL; PinHeader_1x05_P2.54mm_Horizontal; LCSC C32713264
Q1: AO3401A; SOT-23; LCSC C15127
Q2: HJ8205; SOT-23-6; LCSC C20069150
R1, R2: 5.1k; R_0402_1005Metric; LCSC C25905
R3, R21, R22: 10k; R_0402_1005Metric; LCSC C25744
R4: 3.3k; R_0402_1005Metric; LCSC C25890
R5, R6, R9: 1k; R_0402_1005Metric; LCSC C11702
R7, R10, R14, R15, R16, R17, R18, R19: 100k; R_0402_1005Metric; LCSC C25741
R8, R11, R12, R13, R20: 100; R_0402_1005Metric; LCSC C25076
SW1: EIN/AUS; SW_SPDT_MSK12C02; LCSC C431540
SW2: RESET; SW_Push_1P1T_XKB_TS-1187A; LCSC C318884
SW3: BOOT; SW_Push_1P1T_XKB_TS-1187A; LCSC C318884
TP1: TXD0; TestPoint_Pad_1.0x1.0mm
TP2: RXD0; TestPoint_Pad_1.0x1.0mm
TP3: GND; TestPoint_Pad_1.0x1.0mm
U1: ESP32-C3-WROOM-02-N4; ESP32-C3-WROOM-02_JLC; LCSC C2934560
U2: TP4056; SOIC-8-1EP_3.9x4.9mm_P1.27mm_EP2.41x3.3mm; LCSC C16581
U3: DW01A; SOT-23-6; LCSC C351410
U4, U5: ME6211C33M5G-N; SOT-23-5; LCSC C82942
U6: SRV05-4; SOT-23-6; LCSC C558418

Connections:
+3V3: C1.1, C2.1, C8.1, R3.1, R21.1, R22.1, U1.1 (3V3), U4.5 (VOUT), U6.5 (VP)
BATN: C6.2, J2.2, Q2.1 (S1), U3.6 (GND)
BOOT: SW3.1, U1.8 (IO9)
CC1: J1.A5 (CC1), R1.1
CC2: J1.B5 (CC2), R2.1
CHG_PROG: R4.1, U2.2 (PROG)
CHRG: D2.1 (K), U2.7 (~CHRG)
DW_CS: R9.1, U3.2 (CS)
DW_OC: Q2.4 (G2), U3.3 (OC)
DW_OD: Q2.6 (G1), U3.1 (OD)
DW_VCC: C6.1, R8.2, U3.5 (VCC)
EN: C3.1, R3.2, SW2.1, U1.2 (EN)
FET_D: Q2.2 (D), Q2.5 (D)
GND: C1.2, C2.2, C3.2, C4.2, C5.2, C7.2, C8.2, C9.2, C10.2, C11.2, C12.2, D4.1 (K), J1.A1 (GND), J1.A12 (GND), J1.B1 (GND), J1.B12 (GND), J1.S1 (SHIELD), J3.5, Q2.3 (S2), R1.2, R2.2, R4.2, R7.2, R9.2, R10.2, R15.2, R17.2, R19.2, SW1.3 (C), SW2.2, SW3.2, TP3.1, U1.9 (GND), U1.19 (EPAD), U2.1 (TEMP), U2.3 (GND), U2.9 (EP), U4.2 (GND), U5.2 (GND), U6.2 (VN)
LED: R20.1, U1.18 (IO0)
LED_A: D4.2 (A), R20.2
LED_G_A: D3.2 (A), R6.2
LED_R_A: D2.2 (A), R5.2
NRST: R11.1, U1.6 (IO7)
NRST_T: J3.4, R11.2
PWR_EN: SW1.2 (B), U4.3 (EN)
RXD0: TP2.1, U1.11 (RXD/IO20)
STDBY: D3.1 (K), U2.6 (~STDBY)
STRAP_IO2: R22.2, U1.16 (IO2)
STRAP_IO8: R21.2, U1.7 (IO8)
SWCLK: R12.1, U1.4 (IO5)
SWCLK_T: J3.3, R12.2
SWDIO: R13.1, U1.5 (IO6)
SWDIO_T: J3.2, R13.2
TGT_EN: R10.1, U1.10 (IO10), U5.3 (EN)
TXD0: TP1.1, U1.12 (TXD/IO21)
USB_DN: J1.A7 (D-), J1.B7 (D-), U1.13 (IO18/D-), U6.1 (IO1)
USB_DP: J1.A6 (D+), J1.B6 (D+), U1.14 (IO19/D+), U6.3 (IO2)
VBAT: C5.1, J2.1, Q1.3 (D), R8.1, R16.1, U2.5 (BAT)
VBAT_SENSE: C11.1, R16.2, R17.1, U1.3 (IO4)
VBUS: C4.1, D1.2 (A), J1.A4 (VBUS), J1.A9 (VBUS), J1.B4 (VBUS), J1.B9 (VBUS), Q1.1 (G), R5.1, R6.1, R7.1, R18.1, U2.4 (VCC), U2.8 (CE)
VBUS_SENSE: R18.2, R19.1, U1.17 (IO1)
VSYS: C7.1, C9.1, D1.1 (K), Q1.2 (S), SW1.1 (A), U4.1 (VIN), U5.1 (VIN)
VTGT: C10.1, J3.1, R14.1, U5.5 (VOUT)
VTGT_SENSE: C12.1, R14.2, R15.1, U1.15 (IO3)

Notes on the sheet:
USB-C: Laden + Programmieren (native USB)
Lader TP4056 + Power-Path
Akku 1S LiPo + Schutz (BMS)
Ein/Aus + 3,3 V fuer den ESP32
Schaltbare 3,3 V fuer die VCU + Messung
ESP32-C3-WROOM-02-N4
SWD zur Scooter-VCU
Hinweise
Ladestrom R4 = 3,3k -> ca. 360 mA.
Akku < 400 mAh: R4 = 4,7k ... 10k.
Q1 + D1 = Power-Path: mit USB laeuft das
System aus USB, der Akku wird nur geladen.
U5 schaltet die VCU-Versorgung (GPIO10):
Firmware macht Power-Race automatisch.
VTGT_SENSE erkennt eine extern versorgte VCU,
dann wird U5 nicht eingeschaltet.
SWD mit 100 Ohm Serien-R (Kurzschluss/ESD).
U6 VP an +3V3 (nicht VBUS): kein Rueckspeisen
ueber den D+-Pull-up im Akkubetrieb.
IO2/IO8 (Strapping) per 10k auf High, IO9 = BOOT.

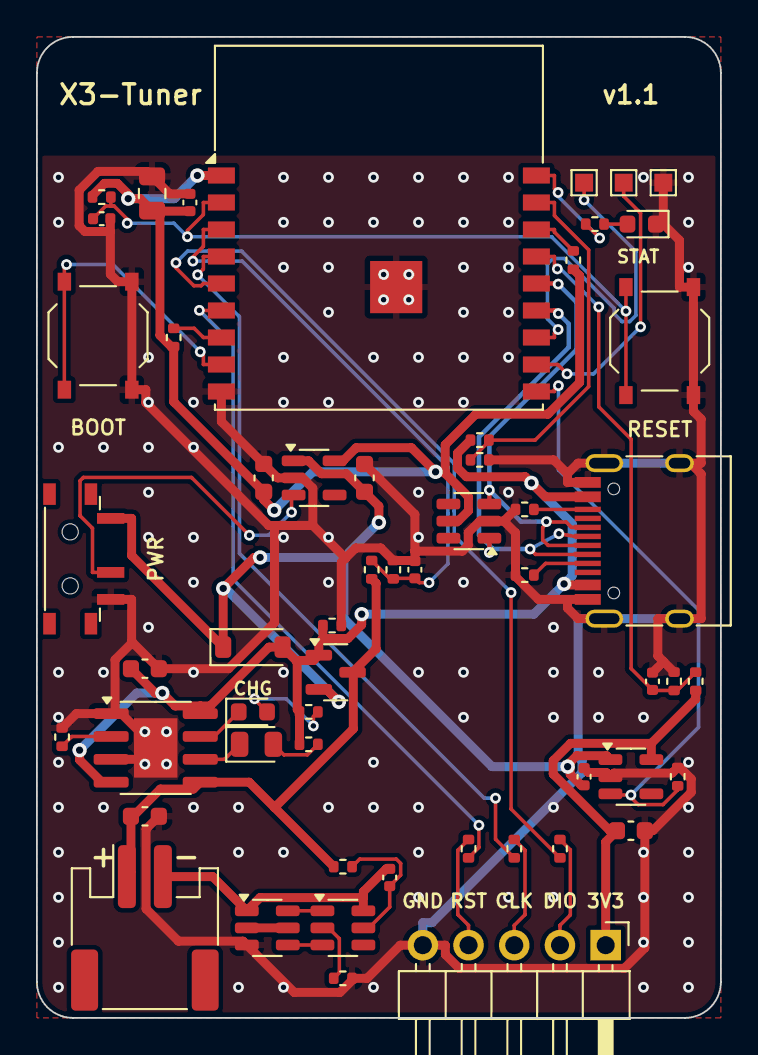
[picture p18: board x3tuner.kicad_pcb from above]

Board: 2 copper layers, 38.0 x 54.5 mm, 61 parts (0 on the bottom side), 40 nets.

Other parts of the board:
KT1, KT2, KT3, KT4, KT5, KT6: Tab

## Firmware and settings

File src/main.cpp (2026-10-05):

// x3utils-esp32 — entry point.
//
// Brings up WiFi (self-hosted hotspot by default, or joins a network), serves
// the web UI, bridges the browser to the SWD operations, and runs the queued
// operation from loop() so the blocking bit-banged SWD never stalls the async
// web stack.

#include <Arduino.h>
#include <ArduinoJson.h>
#include <AsyncTCP.h>
#include <ESPAsyncWebServer.h>
#include <ESPmDNS.h>
#include <Preferences.h>
#include <WiFi.h>

#include "at32.h"
#include "board.h"
#include "config.h"
#include "fw_ident.h"
#include "swd.h"
#include "web_ui.h"
#include "x3_ops.h"

static Swd swd;
static At32 at32(swd);
static X3Ops ops(swd, at32);

static AsyncWebServer server(80);
static AsyncWebSocket ws("/ws");
static Preferences prefs;

// Live settings (loaded from NVS at boot).
struct Settings {
  String wifi = "ap";
  String apSsid = AP_SSID_DEFAULT, apPass = AP_PASSWORD_DEFAULT;
  String staSsid = "", staPass = "";
  int pinClk = PIN_SWCLK_DEFAULT, pinDio = PIN_SWDIO_DEFAULT, pinRst = PIN_NRST_DEFAULT;
  int swdUs = SWD_HALF_CLOCK_US_DEFAULT;
} cfg;

// Upload bookkeeping (raw .bin POST into the shared buffer).
static volatile uint32_t gUploadLen = 0;
static volatile bool gUploadError = false;

// ── Settings persistence ─────────────────────────────────────────────────────
static void loadSettings() {
  prefs.begin("x3cfg", true);
  cfg.wifi = prefs.getString("wifi", cfg.wifi);
  cfg.apSsid = prefs.getString("apSsid", cfg.apSsid);
  cfg.apPass = prefs.getString("apPass", cfg.apPass);
  cfg.staSsid = prefs.getString("staSsid", cfg.staSsid);
  cfg.staPass = prefs.getString("staPass", cfg.staPass);
  cfg.pinClk = prefs.getInt("pinClk", cfg.pinClk);
  cfg.pinDio = prefs.getInt("pinDio", cfg.pinDio);
  cfg.pinRst = prefs.getInt("pinRst", cfg.pinRst);
  cfg.swdUs = prefs.getInt("swdUs", cfg.swdUs);
  prefs.end();
}

static void saveSettings() {
  prefs.begin("x3cfg", false);
  prefs.putString("wifi", cfg.wifi);
  prefs.putString("apSsid", cfg.apSsid);
  prefs.putString("apPass", cfg.apPass);
  prefs.putString("staSsid", cfg.staSsid);
  prefs.putString("staPass", cfg.staPass);
  prefs.putInt("pinClk", cfg.pinClk);
  prefs.putInt("pinDio", cfg.pinDio);
  prefs.putInt("pinRst", cfg.pinRst);
  prefs.putInt("swdUs", cfg.swdUs);
  prefs.end();
}

// ── WiFi ─────────────────────────────────────────────────────────────────────
static void startWifi() {
  if (cfg.wifi == "sta" && cfg.staSsid.length()) {
    WiFi.mode(WIFI_STA);
    WiFi.begin(cfg.staSsid.c_str(), cfg.staPass.c_str());
    Serial.printf("Joining WiFi \"%s\"", cfg.staSsid.c_str());
    uint32_t start = millis();
    while (WiFi.status() != WL_CONNECTED && millis() - start < 15000) { delay(300); Serial.print("."); }
    Serial.println();
    if (WiFi.status() == WL_CONNECTED) {
      Serial.print("Joined. IP: "); Serial.println(WiFi.localIP());
      return;
    }
    Serial.println("Join failed — falling back to hotspot.");
  }
  WiFi.mode(WIFI_AP);
  bool open = cfg.apPass.length() < 8;
  WiFi.softAP(cfg.apSsid.c_str(), open ? nullptr : cfg.apPass.c_str());
  Serial.print("Hotspot \""); Serial.print(cfg.apSsid);
  Serial.print("\" up. Connect, then open http://"); Serial.print(WiFi.softAPIP()); Serial.println("/");
}

// ── WebSocket event sink ─────────────────────────────────────────────────────
static void sinkEvent(const OpEvent &e) {
  JsonDocument doc;
  doc["type"] = e.type;
  if (e.type == "log" || e.type == "stage" || e.type == "done") doc["text"] = e.text;
  if (e.type == "done") doc["ok"] = e.ok;
  if (e.type == "progress") { doc["done"] = e.done; doc["total"] = e.total; doc["phase"] = e.phase; }
  if (e.type == "stage") doc["phase"] = e.phase;
  String out;
  serializeJson(doc, out);
  ws.textAll(out);
}

// ── HTTP helpers ─────────────────────────────────────────────────────────────
static OpMode parseMode(const String &s) {
  if (s == "reset") return OpMode::reset;
  if (s == "race") return OpMode::race;
  return OpMode::normal;
}
static OpKind parseKind(const String &s) {
  if (s == "check") return OpKind::check;
  if (s == "dump") return OpKind::dump;
  if (s == "flashFull") return OpKind::flashFull;
  if (s == "flashSlot0") return OpKind::flashSlot0;
  if (s == "protectionCheck") return OpKind::protectionCheck;
  if (s == "rescue") return OpKind::rescue;
  if (s == "compat") return OpKind::compat;
  return OpKind::none;
}

static void sendJson(AsyncWebServerRequest *req, const String &body, int code = 200) {
  req->send(code, "application/json", body);
}

static void routes() {
  server.addHandler(&ws);

  server.on("/", HTTP_GET, [](AsyncWebServerRequest *req) {
    req->send_P(200, "text/html", INDEX_HTML);
  });

  // Start an operation.
  server.on("/api/op", HTTP_POST, [](AsyncWebServerRequest *req) {},
            nullptr,
            [](AsyncWebServerRequest *req, uint8_t *data, size_t len, size_t index, size_t total) {
    if (index + len != total) return;  // only act on a complete (single-chunk) body
    JsonDocument doc;
    if (deserializeJson(doc, data, len)) { sendJson(req, "{\"ok\":false,\"why\":\"bad JSON\"}"); return; }
    OpKind kind = parseKind(doc["kind"] | "");
    OpMode mode = parseMode(doc["mode"] | "normal");
    String mcu = doc["mcuModel"] | "";
    if (kind == OpKind::none) { sendJson(req, "{\"ok\":false,\"why\":\"unknown op\"}"); return; }
    String why;
    if (!ops.request(kind, mode, mcu, why)) { sendJson(req, String("{\"ok\":false,\"why\":\"") + why + "\"}"); return; }
    sendJson(req, "{\"ok\":true}");
  });

  // Raw .bin upload into the shared buffer (used before a flash op).
  server.on("/api/upload", HTTP_POST,
            [](AsyncWebServerRequest *req) {
    if (gUploadError) { sendJson(req, "{\"ok\":false,\"why\":\"file too large or device busy\"}"); return; }
    ops.setUploadLength(gUploadLen);
    sendJson(req, String("{\"ok\":true,\"len\":") + gUploadLen + "}");
  },
            nullptr,
            [](AsyncWebServerRequest *req, uint8_t *data, size_t len, size_t index, size_t total) {
    if (index == 0) { gUploadLen = 0; gUploadError = ops.busy(); }
    if (gUploadError) return;
    if (total > ops.uploadCapacity() || index + len > ops.uploadCapacity()) { gUploadError = true; return; }
    memcpy(ops.uploadBuffer() + index, data, len);
    gUploadLen = index + len;
  });

  server.on("/api/abort", HTTP_POST, [](AsyncWebServerRequest *req) {
    ops.abort();
    sendJson(req, "{\"ok\":true}");
  });

  server.on("/api/status", HTTP_GET, [](AsyncWebServerRequest *req) {
    JsonDocument doc;
    doc["busy"] = ops.busy();
    doc["haveBackup"] = ops.backupLength() > 0;
    String tn = at32.target().name;
    doc["target"] = (tn.length() && tn != "unknown") ? tn : "no target";
    // X3-Tuner board telemetry (null/false on plain dev boards).
    int vbat = x3board.batteryMillivolts();
    if (vbat >= 0) { doc["vbat"] = vbat; doc["bat"] = x3board.batteryPercent(); }
    doc["usb"] = x3board.usbPresent();
    doc["hasTgtPower"] = x3board.hasTargetPower();
    doc["tgtPower"] = x3board.targetPowered();
    int vtgt = x3board.targetMillivolts();
    if (vtgt >= 0) doc["vtgt"] = vtgt;
    String out; serializeJson(doc, out);
    sendJson(req, out);
  });

  // Switch the board's 3.3 V supply for the VCU (X3-Tuner PCB only).
  server.on("/api/target", HTTP_POST, [](AsyncWebServerRequest *req) {},
            nullptr,
            [](AsyncWebServerRequest *req, uint8_t *data, size_t len, size_t index, size_t total) {
    if (index + len != total) return;  // only act on a complete (single-chunk) body
    JsonDocument doc;
    if (deserializeJson(doc, data, len)) { sendJson(req, "{\"ok\":false,\"why\":\"bad JSON\"}"); return; }
    if (ops.busy()) { sendJson(req, "{\"ok\":false,\"why\":\"an operation is running\"}"); return; }
    String why;
    bool ok = x3board.setTargetPower(doc["on"] | false, why);
    JsonDocument res;
    res["ok"] = ok;
    if (!ok) res["why"] = why;
    String out; serializeJson(res, out);
    sendJson(req, out);
  });

  // Backup download. Defaults to the pre-SHU-patch original; ?patched=1 serves
  // the exact bytes now in flash.
  server.on("/api/backup.bin", HTTP_GET, [](AsyncWebServerRequest *req) {
    uint32_t n = ops.backupLength();
    if (!n) { req->send(404, "text/plain", "no backup yet"); return; }
    bool original = !req->hasParam("patched");
    AsyncWebServerResponse *res = req->beginChunkedResponse(
        "application/octet-stream",
        [original](uint8_t *buffer, size_t maxLen, size_t index) -> size_t {
          uint32_t total = ops.backupLength();
          if (index >= total) return 0;
          size_t chunk = total - index < maxLen ? total - index : maxLen;
          for (size_t i = 0; i < chunk; i++) buffer[i] = ops.backupByteAt(index + i, original);
          return chunk;
        });
    res->addHeader("Content-Disposition", "attachment; filename=x3utils-backup.bin");
    req->send(res);
  });

  server.on("/api/settings", HTTP_GET, [](AsyncWebServerRequest *req) {
    JsonDocument doc;
    doc["wifi"] = cfg.wifi;
    doc["apSsid"] = cfg.apSsid;
    doc["apPass"] = cfg.apPass;
    doc["staSsid"] = cfg.staSsid;
    doc["staPass"] = cfg.staPass;
    doc["pinClk"] = cfg.pinClk;
    doc["pinDio"] = cfg.pinDio;
    doc["pinRst"] = cfg.pinRst;
    doc["swdUs"] = cfg.swdUs;
    JsonArray models = doc["mcuModels"].to<JsonArray>();
    for (auto &m : fwident::mcuModels()) models.add(m);
    String out; serializeJson(doc, out);
    sendJson(req, out);
  });

  server.on("/api/settings", HTTP_POST, [](AsyncWebServerRequest *req) {},
            nullptr,
            [](AsyncWebServerRequest *req, uint8_t *data, size_t len, size_t index, size_t total) {
    if (index + len != total) return;  // only act on a complete (single-chunk) body
    JsonDocument doc;
    if (deserializeJson(doc, data, len)) { sendJson(req, "{\"ok\":false}"); return; }
    cfg.wifi = doc["wifi"] | cfg.wifi;
    cfg.apSsid = doc["apSsid"] | cfg.apSsid;
    cfg.apPass = doc["apPass"] | cfg.apPass;
    cfg.staSsid = doc["staSsid"] | cfg.staSsid;
    cfg.staPass = doc["staPass"] | cfg.staPass;
    cfg.pinClk = doc["pinClk"] | cfg.pinClk;
    cfg.pinDio = doc["pinDio"] | cfg.pinDio;
    cfg.pinRst = doc["pinRst"] | cfg.pinRst;
    cfg.swdUs = doc["swdUs"] | cfg.swdUs;
    saveSettings();
    sendJson(req, "{\"ok\":true}");
    delay(300);
    ESP.restart();
  });

  server.onNotFound([](AsyncWebServerRequest *req) { req->send(404, "text/plain", "not found"); });
}

void setup() {
  Serial.begin(115200);
  delay(200);
  Serial.println("\nx3utils-esp32 starting");

  x3board.begin();  // target supply off first thing
  loadSettings();

  if (!ops.begin()) {
    Serial.println("FATAL: could not allocate the 128 KB working buffer.");
  }
  swd.configure(cfg.pinClk, cfg.pinDio, cfg.pinRst, (uint8_t)cfg.swdUs);
  at32.setLog([](const String &l) { OpEvent e; e.type = "log"; e.text = l; sinkEvent(e); });
  ops.setSink(sinkEvent);

  startWifi();
  if (MDNS.begin(MDNS_HOSTNAME)) {
    MDNS.addService("http", "tcp", 80);
    Serial.printf("mDNS: http://%s.local/\n", MDNS_HOSTNAME);
  }
  routes();
  server.begin();
  Serial.println("Web server up on port 80.");
}

void loop() {
  ops.loopTick();
  x3board.loopTick(ops.busy());
  ws.cleanupClients();
  delay(1);
}

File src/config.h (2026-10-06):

// x3utils-esp32 — build-time configuration.
//
// Pins, WiFi defaults, and SWD timing live here so a user only edits one file.
// Every value can also be changed at runtime from the web UI (Settings panel);
// the values here are the power-on defaults.

#pragma once

#include <Arduino.h>

// ── SWD wiring ───────────────────────────────────────────────────────────────
// Connect these ESP32 GPIOs to the VCU debug header:
//   SWCLK  -> chip SWCLK
//   SWDIO  -> chip SWDIO
//   NRST   -> chip nRST / C45 (optional but strongly recommended)
//   GND    -> common ground (ALWAYS)
//
// Use 3.3 V logic only. Power the VCU from ONE source at a time (main/bench
// power OR the ESP32 3V3 pin) exactly as the upstream x3utils wiki warns.
#if defined(X3_BOARD_TUNER)
// X3-Tuner PCB (hardware/, ESP32-C3-WROOM-02): the SWD trio is on the
// module's left pads, closest to the target header.
static const int PIN_SWCLK_DEFAULT = 5;
static const int PIN_SWDIO_DEFAULT = 6;
static const int PIN_NRST_DEFAULT = 7;
static const int PIN_LED_DEFAULT = 0;
#elif defined(X3_BOARD_C3)
static const int PIN_SWCLK_DEFAULT = 4;
static const int PIN_SWDIO_DEFAULT = 5;
static const int PIN_NRST_DEFAULT = 6;
static const int PIN_LED_DEFAULT = 8;
#elif defined(X3_BOARD_S3)
static const int PIN_SWCLK_DEFAULT = 4;
static const int PIN_SWDIO_DEFAULT = 5;
static const int PIN_NRST_DEFAULT = 6;
static const int PIN_LED_DEFAULT = 48;
#else  // classic ESP32
static const int PIN_SWCLK_DEFAULT = 18;
static const int PIN_SWDIO_DEFAULT = 19;
static const int PIN_NRST_DEFAULT = 21;
static const int PIN_LED_DEFAULT = 2;
#endif

// ── X3-Tuner board extras ────────────────────────────────────────────────────
// Only the X3-Tuner PCB has these; on dev boards they are -1 and the matching
// features (battery gauge, switchable target supply) simply report "absent".
#if defined(X3_BOARD_TUNER)
static const int PIN_TGT_EN = 10;      // high = target LDO (3.3 V to the VCU) on
static const int PIN_VTGT_SENSE = 3;   // ADC1: VTGT through a 1:2 divider
static const int PIN_VBAT_SENSE = 4;   // ADC1: battery through a 1:2 divider
static const int PIN_VBUS_SENSE = 1;   // ADC1: VBUS through a 1:2 divider (USB present)
#else
static const int PIN_TGT_EN = -1;
static const int PIN_VTGT_SENSE = -1;
static const int PIN_VBAT_SENSE = -1;
static const int PIN_VBUS_SENSE = -1;
#endif

// A VCU already showing more than this on its 3V3 pin is powered from
// somewhere else; the board then refuses to switch its own supply on.
static const int TARGET_EXTERNAL_MV = 1000;

// Half-clock delay for the bit-banged SWD line, in microseconds. 0 lets the
// line run as fast as the GPIO API allows (a few hundred kHz on a classic
// ESP32), which is reliable for short cables. Raise to 1–3 if a long or noisy
// cable throws "SWD: no ACK" / parity errors.
static const uint8_t SWD_HALF_CLOCK_US_DEFAULT = 0;

// ── WiFi ─────────────────────────────────────────────────────────────────────
// Default is a self-hosted access point so the iPhone just joins the ESP32's
// own network — no router, no internet. Connect to this SSID, then open
// http://192.168.4.1/ in Safari (or any browser).
//
// You can instead join an existing WiFi from the Settings panel; the choice is
// stored in flash and used on the next boot.
static const char AP_SSID_DEFAULT[] = "x3utils-esp32";
static const char AP_PASSWORD_DEFAULT[] = "x3utils123";  // >= 8 chars, or "" for open
static const char MDNS_HOSTNAME[] = "x3utils";           // http://x3utils.local/

// ── Target geometry (AT32F415, 128 KB) ───────────────────────────────────────
static const uint32_t FLASH_BASE = 0x08000000UL;
static const uint32_t SLOT0_BASE = 0x08001000UL;
static const uint32_t BACKUP_LENGTH = 131072UL;  // 128 KB — the only backup size

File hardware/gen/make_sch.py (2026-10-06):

"""Generate the KiCad 7 schematic (and the project symbol library) from circuit.py.

Every pin gets a short wire stub and a net label (or a no-connect flag), so the
schematic is guaranteed to carry exactly the netlist the PCB was built from.
"""

import os
import re
import sys
import uuid

sys.path.insert(0, os.path.dirname(__file__))
import circuit as C  # noqa: E402
from sexpr import Q, dump, find, find_all, parse  # noqa: E402

HERE = os.path.dirname(os.path.abspath(__file__))
KDIR = os.path.normpath(os.path.join(HERE, "..", "kicad"))
SYMROOT = "/usr/share/kicad/symbols"
SCH = os.path.join(KDIR, C.PROJECT + ".kicad_sch")
LIB = os.path.join(KDIR, C.PROJECT + ".kicad_sym")
ROOT_UUID = str(uuid.uuid5(uuid.NAMESPACE_URL, "x3tuner/root-sheet"))
GRID = 1.27
STUB = 2.54


def uid(*parts):
    return str(uuid.uuid5(uuid.NAMESPACE_URL, "x3tuner/" + "/".join(map(str, parts))))


def sym_uuid(ref):
    return str(uuid.uuid5(uuid.NAMESPACE_URL, "x3tuner/" + ref))


def snap(v):
    return round(round(v / GRID) * GRID, 4)


# ── project symbol library (parts KiCad's stock library lacks) ───────────────
def ic_symbol(name, ref, fp, desc, left, right, width=12.7, datasheet=""):
    """Rectangular IC symbol. left/right: [(number, name, type), ...] top→down."""
    rows = max(len(left), len(right))
    h = (rows + 1) * 2.54
    top = snap(h / 2)
    hw = width / 2
    pins = []
    for side, plist in ((-1, left), (1, right)):
        for i, (num, pname, ptype) in enumerate(plist):
            y = top - 2.54 * (i + 1)
            x = side * (hw + 2.54)
            ang = 0 if side < 0 else 180
            pins.append(
                '      (pin %s line (at %s %s %d) (length 2.54)\n'
                '        (name "%s" (effects (font (size 1.27 1.27))))\n'
                '        (number "%s" (effects (font (size 1.27 1.27))))\n      )\n'
                % (ptype, _n(x), _n(y), ang, pname, num))
    return (
        '  (symbol "%s" (in_bom yes) (on_board yes)\n'
        '    (property "Reference" "%s" (at 0 %s 0) (effects (font (size 1.27 1.27))))\n'
        '    (property "Value" "%s" (at 0 %s 0) (effects (font (size 1.27 1.27))))\n'
        '    (property "Footprint" "%s" (at 0 0 0) (effects (font (size 1.27 1.27)) hide))\n'
        '    (property "Datasheet" "%s" (at 0 0 0) (effects (font (size 1.27 1.27)) hide))\n'
        '    (property "ki_description" "%s" (at 0 0 0) (effects (font (size 1.27 1.27)) hide))\n'
        '    (symbol "%s_0_1"\n'
        '      (rectangle (start %s %s) (end %s %s) (stroke (width 0.254) (type default)) (fill (type background)))\n'
        '    )\n'
        '    (symbol "%s_1_1"\n%s    )\n  )\n'
        % (name, ref, _n(top + 1.27), name, _n(-top - 1.27), fp, datasheet, desc,
           name, _n(-hw), _n(top), _n(hw), _n(-top), name, "".join(pins)))


def _n(v):
    s = ("%.4f" % v).rstrip("0").rstrip(".")
    return "0" if s in ("-0", "") else s


def write_project_lib():
    syms = [
        ic_symbol("TP4056", "U", "Package_SO:SOIC-8-1EP_3.9x4.9mm_P1.27mm_EP2.41x3.3mm",
                  "1A Li-Ion linear charger (ESOP-8)",
                  [("4", "VCC", "power_in"), ("8", "CE", "input"), ("1", "TEMP", "input"),
                   ("2", "PROG", "passive")],
                  [("5", "BAT", "power_out"), ("7", "~{CHRG}", "open_collector"),
                   ("6", "~{STDBY}", "open_collector"), ("3", "GND", "power_in"),
                   ("9", "EP", "passive")],
                  datasheet="https://www.lcsc.com/datasheet/lcsc_datasheet_1809261820_TOPPOWER-Nanjing-Extension-Microelectronics-TP4056-42-ESOP8_C16581.pdf"),
        ic_symbol("DW01A", "U", "Package_TO_SOT_SMD:SOT-23-6",
                  "1S Li-Ion battery protection IC",
                  [("5", "VCC", "power_in"), ("2", "CS", "input"), ("4", "TD", "input"),
                   ("6", "GND", "power_in")],
                  [("1", "OD", "output"), ("3", "OC", "output")], width=10.16),
        ic_symbol("ESP32-C3-WROOM-02", "U", "x3tuner:ESP32-C3-WROOM-02_JLC",
                  "ESP32-C3 WiFi/BLE module, 4 MB flash (pins per Espressif datasheet)",
                  [("1", "3V3", "power_in"), ("2", "EN", "input"), ("3", "IO4", "bidirectional"),
                   ("4", "IO5", "bidirectional"), ("5", "IO6", "bidirectional"),
                   ("6", "IO7", "bidirectional"), ("7", "IO8", "bidirectional"),
                   ("8", "IO9", "bidirectional"), ("9", "GND", "power_in"), ("19", "EPAD", "passive")],
                  [("18", "IO0", "bidirectional"), ("17", "IO1", "bidirectional"),
                   ("16", "IO2", "bidirectional"), ("15", "IO3", "bidirectional"),
                   ("14", "IO19/D+", "bidirectional"), ("13", "IO18/D-", "bidirectional"),
                   ("12", "TXD/IO21", "bidirectional"), ("11", "RXD/IO20", "bidirectional"),
                   ("10", "IO10", "bidirectional")], width=17.78,
                  datasheet="https://www.espressif.com/sites/default/files/documentation/esp32-c3-wroom-02_datasheet_en.pdf"),
        ic_symbol("8205_SOT-23-6", "Q", "Package_TO_SOT_SMD:SOT-23-6",
                  "Dual N-MOSFET, common drain, 1S battery protection (FS8205/HJ8205)",
                  [("1", "S1", "passive"), ("6", "G1", "input"), ("2", "D", "passive")],
                  [("3", "S2", "passive"), ("4", "G2", "input"), ("5", "D", "passive")],
                  width=10.16),
    ]
    with open(LIB, "w") as f:
        f.write("(kicad_symbol_lib (version 20220914) (generator x3tuner_gen)\n")
        f.write("".join(syms))
        f.write(")\n")
    with open(os.path.join(KDIR, "sym-lib-table"), "w") as f:
        f.write('(sym_lib_table\n  (version 7)\n  (lib (name "%s")(type "KiCad")'
                '(uri "${KIPRJMOD}/%s.kicad_sym")(options "")(descr "X3-Tuner project symbols"))\n)\n'
                % (C.PROJECT, C.PROJECT))


# ── symbol loading / flattening ──────────────────────────────────────────────
_libcache = {}


def _lib(name):
    if name not in _libcache:
        path = LIB if name == C.PROJECT else os.path.join(SYMROOT, name + ".kicad_sym")
        _libcache[name] = {str(s[1]): s for s in find_all(parse(open(path).read())[0], "symbol")}
    return _libcache[name]
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

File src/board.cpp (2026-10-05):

#include "board.h"

#include "config.h"

X3Board x3board;

#if defined(X3_BOARD_TUNER)
static const bool kHasLed = true;
#else
// Dev boards: GPIO48 on an S3 DevKit is an addressable RGB LED, so only drive
// the LED on our own PCB.
static const bool kHasLed = false;
#endif

// Both sense dividers are 100k/100k, i.e. the pin sees half the voltage.
static int readDivided(int pin) {
  if (pin < 0) return -1;
  uint32_t sum = 0;
  for (int i = 0; i < 8; i++) sum += analogReadMilliVolts(pin);
  return (int)(sum / 8) * 2;
}

void X3Board::begin() {
  if (PIN_TGT_EN >= 0) {
    digitalWrite(PIN_TGT_EN, LOW);
    pinMode(PIN_TGT_EN, OUTPUT);
  }
  if (PIN_VTGT_SENSE >= 0) analogSetPinAttenuation(PIN_VTGT_SENSE, ADC_11db);
  if (PIN_VBAT_SENSE >= 0) analogSetPinAttenuation(PIN_VBAT_SENSE, ADC_11db);
  if (PIN_VBUS_SENSE >= 0) analogSetPinAttenuation(PIN_VBUS_SENSE, ADC_11db);
  if (kHasLed && PIN_LED_DEFAULT >= 0) {
    pinMode(PIN_LED_DEFAULT, OUTPUT);
    digitalWrite(PIN_LED_DEFAULT, LOW);
  }
}

void X3Board::loopTick(bool busy) {
  if (!kHasLed || PIN_LED_DEFAULT < 0) return;
  uint32_t now = millis();
  // busy: 100 ms on / 100 ms off; idle: 40 ms flash every 2 s
  uint32_t period = busy ? 200 : 2000;
  uint32_t onTime = busy ? 100 : 40;
  bool on = (now - _ledT) % period < onTime;
  if (on != _ledOn) {
    _ledOn = on;
    digitalWrite(PIN_LED_DEFAULT, on ? HIGH : LOW);
  }
}

bool X3Board::hasTargetPower() const { return PIN_TGT_EN >= 0; }

bool X3Board::setTargetPower(bool on, String &why, bool skipExternalCheck) {
  if (!hasTargetPower()) { why = "This board has no switchable target supply."; return false; }
  if (on && !_tgtOn && !skipExternalCheck) {
    int mv = targetMillivolts();
    if (mv > TARGET_EXTERNAL_MV) {
      why = String("VCU already shows ") + mv + " mV — it is powered from another source. "
            "Not switching the tool's supply on.";
      return false;
    }
  }
  digitalWrite(PIN_TGT_EN, on ? HIGH : LOW);
  _tgtOn = on;
  return true;
}

bool X3Board::dischargeTarget(uint32_t timeoutMs) {
  if (!hasTargetPower()) return false;
  digitalWrite(PIN_TGT_EN, LOW);
  _tgtOn = false;
  uint32_t start = millis();
  while (millis() - start < timeoutMs) {
    int mv = targetMillivolts();
    if (mv >= 0 && mv < 300) return true;
    delay(20);
  }
  return false;
}

int X3Board::targetMillivolts() const { return readDivided(PIN_VTGT_SENSE); }
int X3Board::batteryMillivolts() const { return readDivided(PIN_VBAT_SENSE); }

int X3Board::batteryPercent() const {
  int mv = batteryMillivolts();
  if (mv < 0) return -1;
  // Coarse open-circuit curve of a 1S LiPo (good enough for a gauge).
  static const int kMv[] = {3300, 3500, 3600, 3700, 3750, 3800, 3900, 4000, 4100, 4200};
  static const int kPct[] = {0, 5, 10, 25, 40, 50, 65, 80, 92, 100};
  if (mv <= kMv[0]) return 0;
  for (int i = 1; i < 10; i++) {
    if (mv <= kMv[i]) return kPct[i - 1] + (kPct[i] - kPct[i - 1]) * (mv - kMv[i - 1]) / (kMv[i] - kMv[i - 1]);
  }
  return 100;
}

// Read through the ADC: a 5 V VBUS halves to ~2.5 V, right at the S3's
// digital VIH threshold, so a digitalRead() would be unreliable.
bool X3Board::usbPresent() const { return readDivided(PIN_VBUS_SENSE) > 3500; }

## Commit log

2026-10-05 Add standalone ESP32 SWD flasher with browser UI
    Port x3utils to run entirely on an ESP32: the board bit-bangs SWD to the
    AT32F415 VCU itself (no PC, no ST-LINK) and hosts a WiFi web UI controllable
    from any phone browser, including iPhone Safari.
    - swd.cpp: bit-banged ADIv5 SWD master (replaces the ST-LINK transport)
    - at32.cpp: Cortex-M debug + AT32F415 detect/erase/program/verify/FAP rescue,
    ported from the swdart engine (direct word-write path)
    - fw_ident.cpp: banner, factory-state, XTEA and Thumb-2 version gates for the
    SHU-compatible workflow, faithful to upstream's safety allow-list
    - x3_ops.cpp: Check / Backup / Flash full / Flash slot 0 / Check protection /
    Unlock-rescue / SH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
    [config.h, main.cpp]
2026-10-05 Add X3-Tuner PCB: all-in-one ESP32-S3 SWD programmer with battery
    hardware/ holds a complete, DRC-clean KiCad 7 design generated from a
    single source (hardware/gen/circuit.py):
    - ESP32-S3-WROOM-1-N16R8 (16 MB flash, 8 MB PSRAM), native USB on USB-C
    (no USB-UART chip), RESET/BOOT, status LED
    - 1S LiPo: TP4056 charger, DW01A + 8205 protection, AO3401 power path
    - ME6211 3.3 V for the ESP (power switch on its enable) and a second,
    GPIO-switched ME6211 that powers the target VCU, with voltage sensing
    - SWD header (3V3/DIO/CLK/RST/GND) with series resistors; SWD pins on
    the module's bottom edge right above it
    - 38 x 60 mm, 2 layers, single-sided assembly; Gerber/BOM/CPL for
    JLCPCB, schem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
    [x3tuner-bom.csv, x3tuner.kicad_pcb, x3tuner.kicad_sch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]
2026-10-06 Add 3D-printable snap-fit case for the X3-Tuner board
    Parametric OpenSCAD enclosure (~42 x 71 x 17 mm): bottom tray with a
    503450 LiPo bay and PCB supports, lid with flexure RESET/BOOT buttons,
    thin-skin LED windows with light baffles, engraved SWD pin labels, and
    cut-outs for USB-C, the power slide switch and the SWD port. Part
    positions are generated from circuit.py (make_case_data.py), STLs and
    renders by gen/make_case.sh.
    Claude-Session: https://claude.ai/code/session_01RVwXhv4cRLa5H5kfiVg79q
    [board_data.scad, x3tuner-case-bottom.stl, x3tuner-case-lid.stl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]
2026-10-06 Add PCBA provider comparison, neutral BOM and case docs
    - hardware/README: landed-cost comparison for Germany (JLCPCB, NextPCB,
    PCBWay, ALLPCB, AISLER), JLC fee breakdown, coupon step, EU customs
    note (EUR 3 duty since July 2026), case section
    - production/x3tuner-bom-generic.csv with manufacturer part numbers for
    assemblers that don't use LCSC codes
    - case renders trimmed; board unchanged (no Basic/Preferred substitutes
    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
    [x3tuner-bom-generic.csv, x3tuner-case-bottom.stl, x3tuner-case-lid.stl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]
2026-10-06 Add 10-up production panel and volume cost estimate
    JLCPCB's Economic assembly is limited to 2-50 pieces and Standard
    assembly needs boards >= 70 x 70 mm, so 100-500 units need a panel:
    - gen/make_panel.py builds a 5x2 KiKit panel (202 x 139 mm, mouse-bite
    tabs, rails with fiducials/tooling holes, top row rotated so all SWD
    edges face the rails); DRC clean; Gerber/BOM/CPL in production/panel
    - tab positions come from kikit:Tab annotations (circuit.PANEL_TABS),
    placed clear of the USB-C, switch and SWD header edges
    - ESP32 module footprint: antenna keep-out/courtyard trimmed to the
    38 mm board so it no longer spills into neighbouring panel boards
    - README: cost per board for 100/200/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
    [x3tuner-panel-bom.csv, x3tuner.kicad_pcb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]
2026-10-06 Cost-down rev 1.1: ESP32-C3-WROOM-02 and MSK12C02 switch
    Swap the ESP32-S3-WROOM-1-N16R8 for an ESP32-C3-WROOM-02-N4 (about
    1.20-1.55 USD less per board at 100+) and the C&K slide switch for an
    MSK12C02 (about 0.55 USD less), roughly 30 % off the assembled board.
    - new pin plan: SWD on IO5/6/7, sense inputs on ADC1 (IO1/IO3/IO4),
    TGT_EN IO10, LED IO0, BOOT IO9, 10k pull-ups on strapping IO2/IO8
    - USB-C moves to the right edge (USB pre-route generalised for either
    orientation), switch to the left; board shrinks to 38 x 54.5 mm
    - project footprints: C3 module without 0.2 mm EPAD vias and with a
    board-sized antenna keep-out; MSK12C02 land pattern after the EasyEDA
    footprint for C431540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
    [board_data.scad, x3tuner-bom-generic.csv, x3tuner-bom.csv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]
2026-10-06 Restyle case as faceted stick, add see-through and section renders
    The case follows the faceted "stick" look: flat top and bottom, 45 degree
    facets on every edge, chamfered plan corners. RESET/BOOT are now pin-holes
    (paper clip), the LEDs shine through open light slits, the SWD pin names
    are engraved under the end-face slot and the logo is on the bottom.
    The previews show the real board: make_case_data.py exports every small
    part's body from the routed KiCad board, and the battery leads are routed
    to the JST plug. make_case.sh now renders the closed device, a translucent
    x-ray from above and below, a cutaway of the layer stack, an exploded view
    and a dimensioned view sheet (case_sheet.py).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
    [board_data.scad, x3tuner-case-bottom.stl, x3tuner-case-lid.stl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]
2026-10-06 Cut JLC assembly cost, assemble every part, price with live JLC data
    Checked every BOM line live on jlcpcb.com (price, stock, library type):
    - U6: ProTek SRV05-4 (C85364) was out of stock (pre-order, MOQ 30);
    now the pin-identical TECH PUBLIC SRV05-4 (C558418, 219k in stock).
    - D4: the yellow LED is an extended part (+$3 fee); now the basic white
    KT-0603W (C2290) with a 100 R series resistor.
    - J3: the SWD header is now assembled by JLC as well (C32713264, THT),
    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
    [board_data.scad, x3tuner-bom-generic.csv, x3tuner-bom.csv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]
2026-10-06 Add NextPCB "Rev 0" variant: single board with break-off side rails
    NextPCB assembles a customer's first order for free but only accepts boards
    of at least 50 x 50 mm. make_nextpcb.py panelizes the 38 x 54.5 mm board
    with a rail left and right (52 x 54.6 mm, mouse bites at the existing tab
    positions) and writes Gerbers, a CPL in plain KiCad orientation and an MPN
    BOM to production/nextpcb/. make_panel.py's DRC and fab steps are
    parameterised so both variants share them.
    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
    [x3tuner-nextpcb-bom.csv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]
2026-10-06 README: explain module vs. bare ESP32-C3 chip with live JLC prices
    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
2026-10-11 Add X3-Tuner Mini: carrier board for a plug-in ESP32-C3 SuperMini
    A cheaper alternative to the WROOM board. A ready-made ESP32-C3 SuperMini
    plugs into two 1x8 sockets, and the 38 x 50 mm carrier adds:
    - TP4056 charger fed from the SuperMini's 5V pin (= USB VBUS);
    - an on/off switch that drives a P-MOSFET gate;
    - the battery path through a Schottky into the 5V pin, which blocks while
    USB is present;
    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
2026-10-11 X3-Tuner Mini as a stick: narrow carrier board and 3D-printed case
    Carrier board (Rev 1.1) redesigned as a 20.5 x 65 mm stick: the
    SuperMini sits at the front with its USB-C in the end face, the SWD
    header at the rear, the charger between the socket rows. New P-MOSFET
    Q3 as battery reverse-polarity protection (cheap JST-PH cells often
    have swapped leads), charge current lowered to ~235 mA (R1 = 5.1k) for
    300-400 mAh cells. Routed, DRC clean; panel and NextPCB rail variant
    (12 mm rails, 50.6 x 65 mm) regenerated.
    Case: the X3-Tuner case model is now a shared core (case_core.scad)
    with one small wrapper per board; the X3-Tuner STLs are unchanged.
    New options for the stick: USB-C in the end fa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
2026-10-11 X3-Tuner Mini Rev 1.2: pin headers, closed case, Wi-Fi OTA + flash lock
    The ESP32-C3 SuperMini has no pins, so the carrier now carries two 1x8
    male headers (factory-soldered); the module is pushed on and clamped by
    the lid. Same pads/routing as the sockets, DRC clean; panel and NextPCB
    variant regenerated. The header's LCSC number could not be verified
    (jlcpcb.com unreachable) and is left blank in the BOM; make_fab/make_panel
    now keep LCSC-less parts in the BOM/CPL and warn, instead of silently
    dropping them.
    Case: no openings over the SuperMini — RESET/BOOT are unreachable and the
    module is fully enclosed. The module sits flat on the headers (not on tall
    sockets), so the case is driven b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
2026-10-15 Remove the X3 bottom engraving from the Mini case
    The underside logo is now configurable (CASE_LOGO / CASE_LOGO_SUB); the
    X3-Tuner Mini case sets both to "" so the case carries no "X3" branding.
    The X3-Tuner case keeps its engraving and its STLs are unchanged.
    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
